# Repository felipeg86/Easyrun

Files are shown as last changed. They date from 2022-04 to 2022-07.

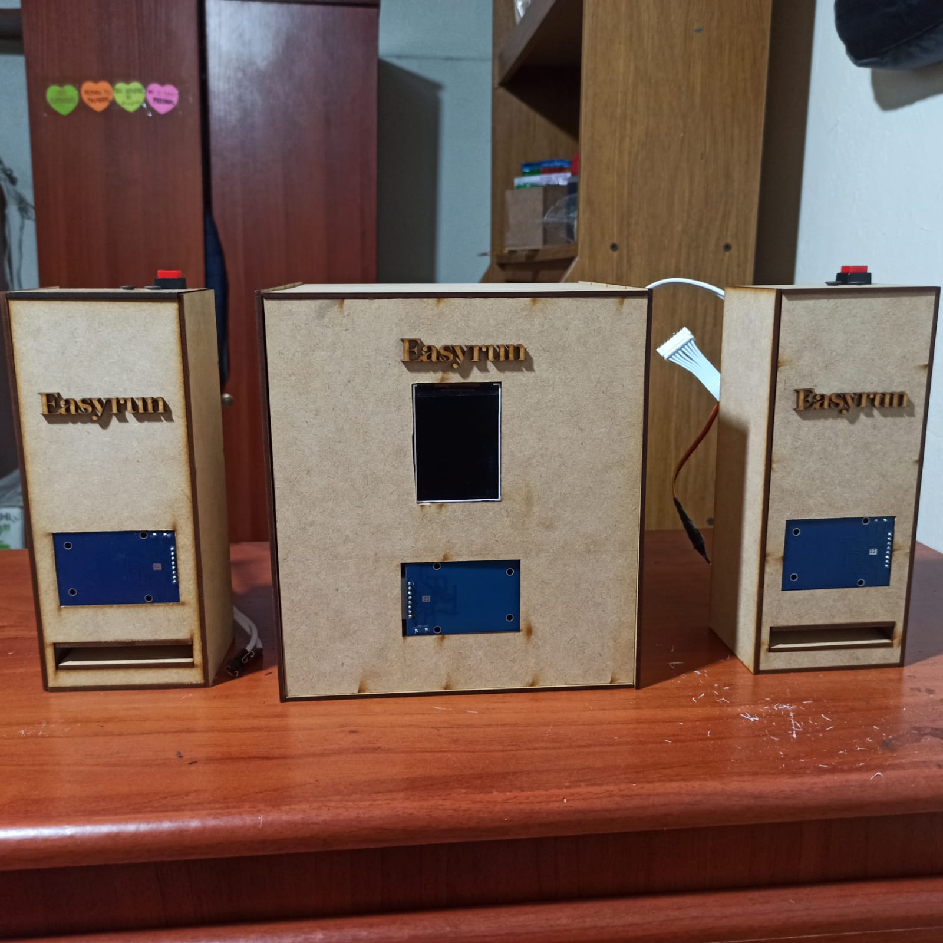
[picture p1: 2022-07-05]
Images/Resultado Final.jpg

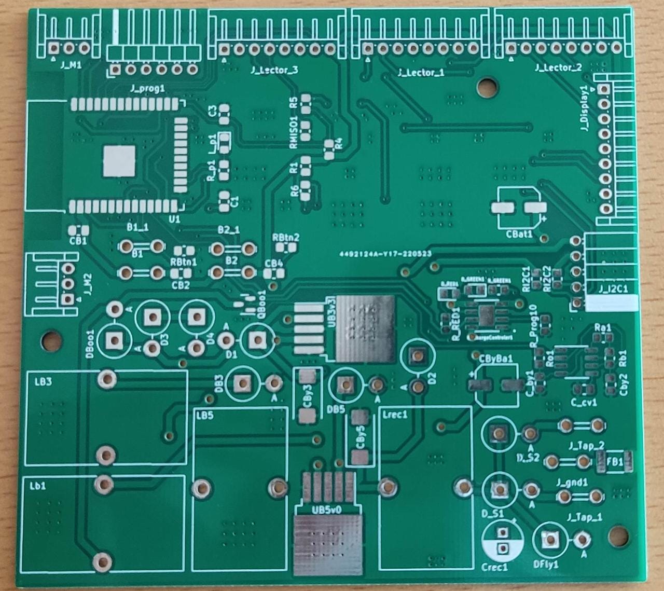
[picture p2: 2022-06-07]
Images/Fabricación placa 2_0.jpeg

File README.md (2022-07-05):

# Easyrun :bike:

Sistema de automatización de préstamo de bicicletas dentro del campus de la Universidad Nacional de Colombia, incorporando la conexión entre estaciones y facilitando el proceso que a la fecha se implementa. El sistema tiene como objetivo principal, reducir los tiempos en el uso del servicio, especialmente en los puntos de prestámo y entrega, además de permitir un control sobre la trazabilidad de cada bicicleta.

Integrantes: 

* Ana Milena Espinosa Jiménez
* Laura Valentina Moreno Castro
* Johan Stevens Higuera Espinel
* Omar Andrés Cely Villate
* Juan Felipe González Pardo
* Kishvari Osorio Delgado
* Johan Sebastian Molina Martinez

## Organización del repositorio

El proyecto se organiza en las sigueintes carpetas:

> * En la carpeta "[Circuit Design](https://github.com/felipeg86/Easyrun/tree/main/Circuit%20Design)" se encuentran las simulaciones, diseños y esquemáticos llevados a cabo en el diseño del hardware del sistema.
> * "[Micropython](https://github.com/felipeg86/Easyrun/tree/main/Micropython)" contiene los scripts utilizados para programar el microcontrolador de la solución.
> * En "[Case Design](https://github.com/felipeg86/Easyrun/tree/main/Case%20Design)" se encuentran los modelos 3D, planos y consideraciones físicas para la cubierta y componentes mecánicos. 
> * "[Budget](https://github.com/felipeg86/Easyrun/tree/main/Budget)" contiene el presupuesto detallado para el desarrollo del prototipo. 
> * "[Imágenes](https://github.com/felipeg86/Easyrun/tree/main/Images)" almacena las imágenes utilizadas en la documentación y en los archivos readme de cada sección.

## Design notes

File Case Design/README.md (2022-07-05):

# Diseño de la carcasa
Para el diseño de las carcasas del sistema, se descargó el modelo 3D de la placa del circuito en KiCad y se cargaron los componentes en 3D, lo cual permitió diseñar en el programa Fusion 360 una caja para la PCB y otra para el seguro. El procedimiento de estos diseños se encuentra en el apartado "Diseño de la Caja" en la wiki del proyecto.

## Contenido Carpeta
La presenta carpeta contiene los siguientes archivos:
 * Archivo modelo 3D placa del circuito (.step)
 * Archivo Corte Láser y modelo 3D para la caja para la PCB (.dxf -- .step)
 * Archivo Corte Láser y modelo 3D para la caja del sistema de bloqueo (.dxf -- .step)
 * Archivo Corte Láser y modelo 3D para el seguro de la bicicleta (.dxf -- .step)

## Diseño Final Caja para la PCB



## Diseño Final Caja para el Sistema de Bloqueo


## Animación Soporte para el Seguro de la Bicicleta
 

## Enlaces de Referencia para los Modelos 3D de los Componentes utilizados:
* Lector y Tarjeta RFID: [https://grabcad.com/library/mfrc522-simple-model-1](https://grabcad.com/library/mfrc522-simple-model-1) 
* Bobina: [https://www.3dcontentcentral.com/download-model.aspx?catalogid=171&id=808719](https://www.3dcontentcentral.com/download-model.aspx?catalogid=171&id=808719) 
* Conector AC: [https://grabcad.com/library/ac-power-socket-3-pin-250v-10a-ac-17-iec3-c14-1](https://grabcad.com/library/ac-power-socket-3-pin-250v-10a-ac-17-iec3-c14-1)
* Tranformador: [https://grabcad.com/library/transformador-chapas-n-75-1](https://grabcad.com/library/transformador-chapas-n-75-1)
* Display: [https://grabcad.com/library/tft-3-5-spi-480x320-v2-0-1](https://grabcad.com/library/tft-3-5-spi-480x320-v2-0-1)
* Interruptor: [https://grabcad.com/library/push-button-switch-with-led-1](https://grabcad.com/library/push-button-switch-with-led-1)

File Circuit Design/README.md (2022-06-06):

## Organización de la carpeta
### En "[Datasheets](https://github.com/felipeg86/Easyrun/tree/main/Circuit%20Design/Datasheets)" se presentan las hojas de datos y especificaciones de algunos de los componentes de hardware utilizados en la solución.
### "[LTspice Simulations](https://github.com/felipeg86/Easyrun/tree/main/Circuit%20Design/LTspice%20Simulations)" contiene las simulaciones realizadas para el diseño y validación de algunos de los subsistemas.
### "[Final Schematic](https://github.com/felipeg86/Easyrun/tree/main/Circuit%20Design/Final%20Schematic)" almacena los archivos de diseño y fabricación de la placa de circuito impreso del sistema.

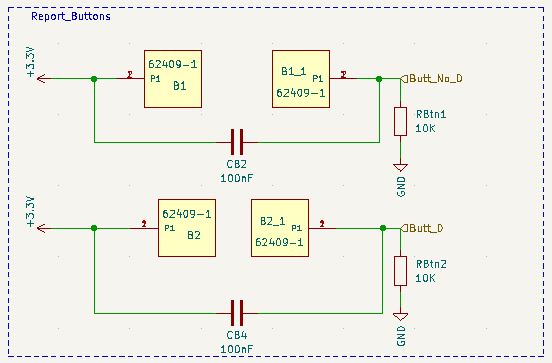
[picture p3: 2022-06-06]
Images/Botones_reporte.JPG

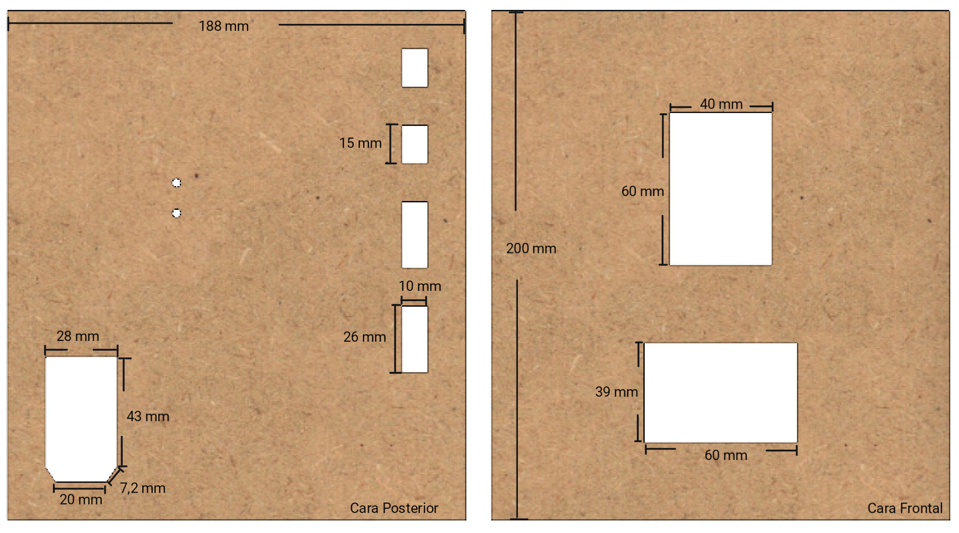
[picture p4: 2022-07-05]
Images/posterior frontal.png

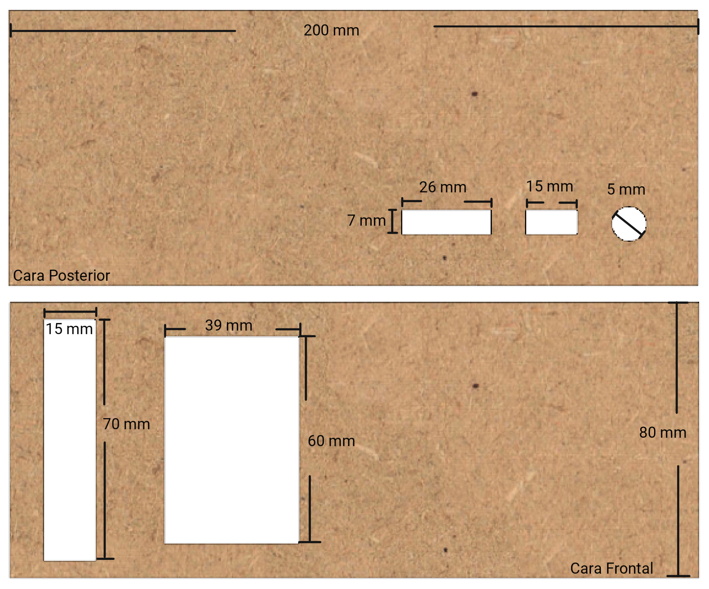
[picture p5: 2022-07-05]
Images/SEGURO1 posterior frontal.png

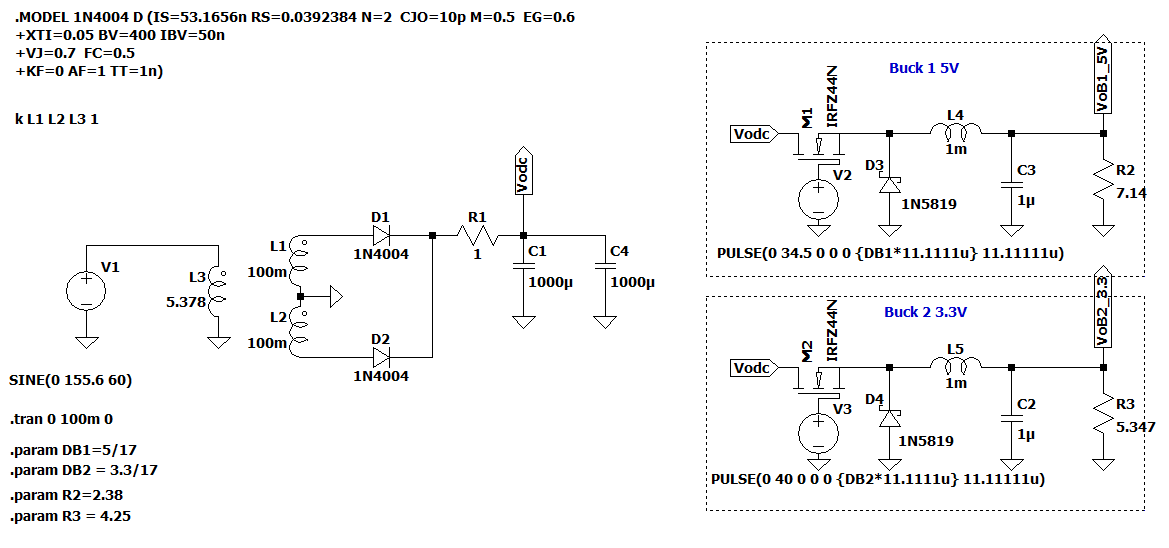
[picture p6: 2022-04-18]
Images/Simulation Power Suply.png

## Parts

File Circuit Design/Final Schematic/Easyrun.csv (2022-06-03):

Source: | Easyrun.kicad_sch
Date: | mar 24 may 2022 09:25:52
Component Count: | 75
Ref | Qnty | Value | Cmp name | Footprint | Description | Vendor
B1, B2, | 2 | 62409-1 | 62409-1 | TE_62409-1
B1_1, | 1 | 62409-1 | 62409-1 | TE_62409-1
B2_1, | 1 | 62409-1 | 62409-1 | TE_62409-1
BProg1, | 1 | SW_DIP_x02 | SW_DIP_x01 | Button_Switch_SMD:SW_SPST_CK_RS282G05A3 | 1x DIP Switch, Single Pole Single Throw (SPST) switch, small symbol
BRst1, | 1 | SW_DIP_x01 | SW_DIP_x01 | Button_Switch_SMD:SW_SPST_CK_RS282G05A3 | 1x DIP Switch, Single Pole Single Throw (SPST) switch, small symbol
BT1, | 1 | Battery_Cell | Battery_Cell | Battery:BatteryHolder_MPD_BH-18650-PC2 | Single-cell battery
C1, C3, | 2 | 100nF | C | Capacitor_SMD:C_0805_2012Metric_Pad1.18x1.45mm_HandSolder | Unpolarized capacitor
C_b1, | 1 | C_Polarized | C_Polarized | Capacitor_SMD:CP_Elec_6.3x5.8 | Polarized capacitor
C_by1, | 1 | 10n | C | Capacitor_SMD:C_0805_2012Metric_Pad1.18x1.45mm_HandSolder | Unpolarized capacitor
C_cv1, | 1 | 10n | C | Capacitor_SMD:C_0805_2012Metric_Pad1.18x1.45mm_HandSolder | Unpolarized capacitor
CB1, CB2, CB4, | 3 | 100nF | C | Capacitor_SMD:C_0805_2012Metric_Pad1.18x1.45mm_HandSolder | Unpolarized capacitor
CB3, CB5, | 2 | 22u | C_Polarized | Capacitor_SMD:CP_Elec_6.3x5.8 | Polarized capacitor
CBat1, | 1 | 10u | C_Polarized | Capacitor_SMD:CP_Elec_6.3x5.8 | Polarized capacitor
Cby2, | 1 | 0.1u | C | Capacitor_SMD:C_0805_2012Metric_Pad1.18x1.45mm_HandSolder | Unpolarized capacitor
CBy3, CBy5, | 2 | 47u | C_Polarized | Capacitor_Tantalum_SMD:CP_EIA-7343-43_Kemet-X_Pad2.25x2.55mm_HandSolder | Polarized capacitor
CByBa1, | 1 | 10u | C_Polarized | Capacitor_SMD:CP_Elec_6.3x5.8 | Polarized capacitor
Crec1, | 1 | 100u | C_Polarized | Capacitor_THT:CP_Radial_D6.3mm_P2.50mm | Polarized capacitor
D1, D2, D3, D4, | 4 | 1N5822 | 1N5822 | Diode_THT:D_DO-201AE_P5.08mm_Vertical_AnodeUp | 40V 3A Schottky Barrier Rectifier Diode, DO-201AD
D_GREEN1, | 1 | LED | LED | LED_SMD:LED_0805_2012Metric_Pad1.15x1.40mm_HandSolder | Light emitting diode
D_RED1, | 1 | LED | LED | LED_SMD:LED_0805_2012Metric_Pad1.15x1.40mm_HandSolder | Light emitting diode
D_S1, D_S2, | 2 | 1N5822 | 1N5822 | Diode_THT:D_DO-201AE_P5.08mm_Vertical_AnodeUp | 40V 3A Schottky Barrier Rectifier Diode, DO-201AD
DB3, DB5, | 2 | 1N5822 | 1N5822 | Diode_THT:D_DO-201AE_P5.08mm_Vertical_AnodeUp | 40V 3A Schottky Barrier Rectifier Diode, DO-201AD
DBoo1, | 1 | 1N5819 | 1N5819 | Diode_THT:D_DO-201AE_P5.08mm_Vertical_AnodeUp | 40V 1A Schottky Barrier Rectifier Diode, DO-41
DFly1, | 1 | 1N5822 | 1N5822 | Diode_THT:D_DO-201AE_P5.08mm_Vertical_AnodeUp | 40V 3A Schottky Barrier Rectifier Diode, DO-201AD
FB1, | 1 | FerriteBead | FerriteBead | Resistor_SMD:R_1812_4532Metric_Pad1.30x3.40mm_HandSolder | Ferrite bead
J_Display1, | 1 | Conn_01x09 | Conn_01x09 | Connector_JST:JST_EH_S9B-EH_1x09_P2.50mm_Horizontal | Generic connector, single row, 01x09, script generated (kicad-library-utils/schlib/autogen/connector/)
J_gnd1, | 1 | 62409-1 | 62409-1 | TE_62409-1
J_I2C1, | 1 | Conn_01x05_Male | Conn_01x05_Male | Connector_PinSocket_2.54mm:PinSocket_1x05_P2.54mm_Horizontal | Generic connector, single row, 01x05, script generated (kicad-library-utils/schlib/autogen/connector/)
J_Lector_1, J_Lector_2, J_Lector_3, | 3 | Conn_01x08 | Conn_01x08 | Connector_JST:JST_EH_S8B-EH_1x08_P2.50mm_Horizontal | Generic connector, single row, 01x08, script generated (kicad-library-utils/schlib/autogen/connector/)
J_M1, J_M2, | 2 | Conn_01x03 | Conn_01x03 | Connector_JST:JST_EH_S3B-EH_1x03_P2.50mm_Horizontal | Generic connector, single row, 01x03, script generated (kicad-library-utils/schlib/autogen/connector/)
J_prog1, | 1 | Conn_01x06_Male | Conn_01x06_Male | Connector_PinHeader_2.54mm:PinHeader_1x06_P2.54mm_Horizontal | Generic connector, single row, 01x06, script generated (kicad-library-utils/schlib/autogen/connector/)
J_Tap_1, J_Tap_2, | 2 | 62409-1 | 62409-1 | TE_62409-1
L_p1, | 1 | LED | LED | LED_SMD:LED_0805_2012Metric_Pad1.15x1.40mm_HandSolder | Light emitting diode
Lb1, | 1 | 100u | L | Inductor_THT:L_Toroid_Vertical_L25.4mm_W14.7mm_P12.20mm_Vishay_TJ5_BigPads | Inductor
LB3, LB5, | 2 | 100u | L | Inductor_THT:L_Toroid_Vertical_L25.4mm_W14.7mm_P12.20mm_Vishay_TJ5_BigPads | Inductor
Lrec1, | 1 | 150m | L | Inductor_THT:L_Toroid_Vertical_L25.4mm_W14.7mm_P12.20mm_Vishay_TJ5_BigPads | Inductor
QBoo1, | 1 | SI2302 | Q_NMOS_GSD | Package_TO_SOT_SMD:SOT-23 | N-MOSFET transistor, gate/source/drain
R1, R4, | 2 | 10K | R | Resistor_SMD:R_0805_2012Metric_Pad1.20x1.40mm_HandSolder | Resistor
R5, R6, | 2 | 220 | R | Resistor_SMD:R_0805_2012Metric_Pad1.20x1.40mm_HandSolder | Resistor
R_GREEN1, | 1 | 1k | R | Resistor_SMD:R_0805_2012Metric_Pad1.20x1.40mm_HandSolder | Resistor
R_p1, | 1 | 47 | R | Resistor_SMD:R_0805_2012Metric_Pad1.20x1.40mm_HandSolder | Resistor
R_Prog10, | 1 | 10k | R | Resistor_SMD:R_0805_2012Metric_Pad1.20x1.40mm_HandSolder | Resistor
R_RED1, | 1 | 1k | R | Resistor_SMD:R_0805_2012Metric_Pad1.20x1.40mm_HandSolder | Resistor
Ra1, | 1 | 47 | R | Resistor_SMD:R_0805_2012Metric_Pad1.20x1.40mm_HandSolder | Resistor
Rb1, | 1 | 100 | R | Resistor_SMD:R_0805_2012Metric_Pad1.20x1.40mm_HandSolder | Resistor
RBtn1, RBtn2, | 2 | 10K | R | Resistor_SMD:R_0805_2012Metric_Pad1.20x1.40mm_HandSolder | Resistor
RI2C1, RI2C2, | 2 | 10k | R | Resistor_SMD:R_0805_2012Metric_Pad1.20x1.40mm_HandSolder | Resistor
RMISO1, | 1 | 10k | R | Resistor_SMD:R_0805_2012Metric_Pad1.20x1.40mm_HandSolder | Resistor
Ro1, | 1 | 1k | R | Resistor_SMD:R_0805_2012Metric_Pad1.20x1.40mm_HandSolder | Resistor
SWRec1, | 1 | SW_DIP_x01 | SW_DIP_x01 | Connector_PinHeader_2.54mm:PinHeader_1x02_P2.54mm_Vertical_SMD_Pin1Left | 1x DIP Switch, Single Pole Single Throw (SPST) switch, small symbol
U1, | 1 | ESP32-WROOM-32 | ESP32-WROOM-32 | RF_Module:ESP32-WROOM-32 | RF Module, ESP32-D0WDQ6 SoC, Wi-Fi 802.11b/g/n, Bluetooth, BLE, 32-bit, 2.7-3.6V, onboard antenna, SMD
U_555, | 1 | LM555xM | LM555xM | Package_SO:SOIC-8_3.9x4.9mm_P1.27mm | Timer, 555 compatible, SOIC-8
U_ChargeControler1, | 1 | TP4056 | TP4056 | TP4056_Bcharge:SOP127P600X175-9N
UB3v3, | 1 | LM2576S-3.3 | LM2576S-3.3 | Package_TO_SOT_SMD:TO-263-5_TabPin3 | 3.3V, 3A SIMPLE SWITCHER® Step-Down Voltage Regulator, TO-263
UB5v0, | 1 | LM2576S-5 | LM2576S-5 | Package_TO_SOT_SMD:TO-263-5_TabPin3 | 5V, 3A SIMPLE SWITCHER® Step-Down Voltage Regulator, TO-263

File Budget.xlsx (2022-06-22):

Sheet: Presupuesto
Item | Qty | Reference(s) | Voltage (V) | Current (A) | Power (W) | Value | Companie | Unit Price | Total Quantity | We have | Condition | Who? | Total
1 | 1 | MicroUSB a Serial CP2102 | 3.3 | 0.02 | 0.066 | $9000 | Ferretrónica | $9000 | 2 | 0 | 2 | Omar | $18000
2 | 1 | ESP32 Wroom 32 | 3.3 | 0.17 | 0.561 | $18000 | Mactrónica | $18000 | 2 |  | 2 | Felipe | $36000
3 | 1 | TFT ILI9341 | 3.3 | 0.06 | 0.198 | $45000 | Mercado Libre | $45000 | 2 |  | 2 | Kish | $90000
4 | 1 | Transformador 12V 1A con Tap Central | - | - | - | $37000 | Ferretrónica | $37000 | 2 |  | 2 | Omar | $74000
5 | 1 | Cable de alimentación C14 | - | - | - | $9900 | Mercado Libre | $9900 | 2 |  | 2 | Felipe | $19800
6 | 1 | Conector de poder ACLEC320C14 | - | - | - | $8800 | Mercado Libre | $8800 | 2 |  | 2 | Felipe | $17600
7 | 2 | Servomotor | 5 | 0.7 | 3.5 | $11000 | Mercado Libre | $11000 | 4 |  | 4 | Sebastian | $44000
8 | 2 | Mecanismo piñon cremallera | - | - | - | $11500 | Mercado Libre | $11500 | 4 |  | 4 | Sebastian | $46000
9 | 2 | Pasador | - | - | - | $4000 | Ferreteria | $4000 | 4 |  | 4 | Sebastian | $16000
10 | 3 | Kit lector RFID RC522 | 3.3 | 0.03 | 0.099 | $15000 | Sigma | $15000 | 6 |  | 6 | Johan | $90000
11 | 7 | Terminal faston macho para PCB | - | - | - | $214.23 | Vistronica | $214.23 | 14 | 0 | 14 | Omar | $2999.22
12 | 7 | Terminal Faston Hembra | - | - | - | $200 | Vistronica | $200 | 14 | 0 | 14 | Omar | $2800
13 | 3 | Alambre AWG 18 (por metros) | - | - | - | $1000 | Ferreteria | $1000 | 6 | 0 | 6 | Sebastian | $6000
14 | 2 | Pulsador 3x6x2.5 mm SMD | - | - | - | $119.05 | Vistronica | $119.05 | 4 | 0 | 4 | Omar | $476.2
15 | 1 | PORTAPILAS 18650 | - | - | - | $5000 | Mactrónica | $5000 | 2 | 0 | 2 | Felipe | $10000
16 | 1 | Capacitor Cerámico 100 nF 50V SAMSUNG SMD 0805 x10 | - | - | - | $996.63 | Vistronica | $996.63 | 2 | 0 | 2 | Omar | $1993.26
17 | 1 | Capacitor Cerámico 10 nF 50V YAGEO SMD 0805 x10 | - | - | - | $484.33 | Vistronica | $484.33 | 2 | 0 | 2 | Omar | $968.66
18 | 3 | COND 47UF 16V | - | - | - | $476 | Sigma | $476 | 6 | 0 | 6 | Johan | $2856
19 | 2 | Capacitor Electrolítico De Aluminio 10 uF 50V 5x5 mm SMD | - | - | - | $217.18 | Vistronica | $217.18 | 4 | 0 | 4 | Omar | $868.72
20 | 2 | Condensador De Tantalio 47 uF 25V SMD EIA7343-43 | - | - | - | $597.38 | Vistronica | $597.38 | 4 | 0 | 4 | Omar | $2389.52
21 | 1 | Condensador Electrolitico 100uF x 35V | - | - | - | $250 | Ferretrónica | $250 | 2 | 0 | 2 | Omar | $500
22 | 11 | Diodo Rectificador De Barrera 1N5822 | - | - | - | $476 | Vistronica | $476 | 22 | 0 | 22 | Omar | $10472
23 | 2 | LED 0805 ROJO | - | - | - | $238 | Sigma | $238 | 4 | 0 | 4 | Johan | $952
24 | 2 | LED 0805 Verde | - | - | - | $238 | Sigma | $238 | 4 | 0 | 4 | Johan | $952
25 | 1 | MI1812K121R | - | - | - | $2142 | Sigma | $2142 | 2 | 0 | 2 | Johan | $4284
26 | 6 | CABLE CON CONECTOR XH2.54MM 8P | - | - | - | $1794 | Vistronica | $1794 | 12 | 0 | 12 | Omar | $21528
27 | 6 | CONECTOR XH2.54 8P MACHO INCLINADO 90 GRADOS | - | - | - | $595 | Vistronica | $595 | 12 | 0 | 12 | Omar | $7140
28 | 1 | CABLE CON CONECTOR XH2.54MM 9P | - | - | - | $2181 | Vistronica | $2181 | 2 | 0 | 2 | Omar | $4362
29 | 2 | CONECTOR MACHO XH2.54 9P | - | - | - | $307 | Vistronica | $307 | 4 | 0 | 4 | Omar | $1228
30 | 2 | CABLE CON CONECTOR XH2.54 MM 3P | - | - | - | $974 | Vistronica | $974 | 4 | 0 | 4 | Omar | $3896
31 | 3 | CONECTOR MACHO XH2.54 8P | - | - | - | $307 | Vistronica | $307 | 6 | 0 | 6 | Omar | $1842
32 | 6 | CONECTOR MACHO XH2.54 3P | - | - | - | $221 | Vistronica | $221 | 12 | 0 | 12 | Omar | $2652
33 | 2 | LED 0805 AZUL | - | - | - | $238 | Sigma | $238 | 4 | 0 | 4 | Johan | $952
34 | 3 | Inductor 100uh 6a Bobina Con Nucleo Toroidal De Ferrita | - | - | - | $7212 | Mercado Libre | $7212 | 6 | 6 | 0 | Felipe | $43272
35 | 2 | TRANSISTOR MOSFET SI2302/A2SHB 20V 3A SMD SOT-23 | - | - | - | $174.93 | Vistronica | $174.93 | 4 | 0 | 4 | Omar | $699.72
36 | 1 | Resistencias 10 KOHM SMD 0805 1/8W 1% x10 | - | - | - | $290.36 | Vistronica | $290.36 | 2 | 0 | 2 | Omar | $580.72
37 | 1 | Resistencias 1 KOHM SMD 0805 1/8W 1% x10 | - | - | - | $290 | Vistronica | $290 | 2 | 0 | 2 | Omar | $580
38 | 1 | Resistencias 47 KOHM SMD 0805 1/8W 1% x10 | - | - | - | $290 | Vistronica | $290 | 2 | 0 | 2 | Omar | $580
39 | 1 | Resistencias 220 OHM SMD 0805 1/8W 1% x10 | - | - | - | $290 | Vistronica | $290 | 2 | 0 | 2 | Omar | $580
40 | 10 | R0805 100 OHM | - | - | - | $48 | Sigma | $48 | 20 | 0 | 20 | Johan | $960
41 | 1 | Conector Jumper 2.54 mm 2P Negro | - | - | - | $119 | Vistronica | $119 | 2 | 0 | 2 | Omar | $238
42 | 1 | Regleta Conector 1*40P 2.54MM Macho-Macho | - | - | - | $312.97 | Vistronica | $312.97 | 2 | 0 | 2 | Omar | $625.94
43 | 1 | TEMPORIZADOR ELÉCTRICO NE555 SMD SOIC-8 | - | - | - | $341.23 | Vistronica | $341.23 | 2 | 0 | 2 | Omar | $682.46
44 | 1 | TP4056 | - | - | - | $2142 | Sigma | $2142 | 2 | 0 | 2 | Johan | $4284
45 | 1 | LM2576S-5.0 | - | - | - | $3332 | Sigma | $3332 | 2 | 0 | 2 | Johan | $6664
46 | 1 | LM2576S-3.3 | - | - | - | $3451 | Sigma | $3451 | 2 | 0 | 2 | Johan | $6902
47 | 1 | EA77-625 | - | - | - | $47600 | Sigma | $47600 | 2 | 0 | 2 | Johan | $95200
48 | 1 | CP2102 | - | - | - | $19180 | Ferretrónica | $19180 | 1 | 0 | 1 | Laura | $19180
Total |  |  |  |  |  |  |  |  |  |  |  |  | $724540.42
 |  |  |  |  |  |  |  |  |  |  |  | Quote | $103505.7743
 |  |  |  |  |  | Each person |  | Quote
 |  |  |  |  |  | Kish |  | $103505.7743
 |  |  |  |  |  | Omar |  | $103505.7743
 |  |  |  |  |  | Felipe |  | $103505.7743
 |  |  |  |  |  | Laura |  | $103505.7743
 |  |  |  |  |  | Ana |  | $103505.7743
 |  |  |  |  |  | Johan |  | $103505.7743
 |  |  |  |  |  | Sebastián |  | $103505.7743

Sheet: Vistronica
Item | Qty | Reference(s) | Value | Companie | Unit Price | Total Quantity | We have | Condition | Who? | Total
11 | 7 | Terminal faston macho para PCB | $214.23 | Vistronica | $214.23 | 14 | 0 | 14 | Omar | $2999.22
12 | 7 | Terminal Faston Hembra | $200 | Vistronica | $200 | 14 | 0 | 14 | Omar | $2800
14 | 2 | Pulsador 3x6x2.5 mm SMD | $119.05 | Vistronica | $119.05 | 4 | 0 | 4 | Omar | $476.2
16 | 1 | Capacitor Cerámico 100 nF 50V SAMSUNG SMD 0805 x10 | $996.63 | Vistronica | $996.63 | 2 | 0 | 2 | Omar | $1993.26
17 | 1 | Capacitor Cerámico 10 nF 50V YAGEO SMD 0805 x10 | $484.33 | Vistronica | $484.33 | 2 | 0 | 2 | Omar | $968.66
19 | 2 | Capacitor Electrolítico De Aluminio 10 uF 50V 5x5 mm SMD | $217.18 | Vistronica | $217.18 | 4 | 0 | 4 | Omar | $868.72
20 | 2 | Condensador De Tantalio 47 uF 25V SMD EIA7343-43 | $597.38 | Vistronica | $597.38 | 4 | 0 | 4 | Omar | $2389.52
22 | 11 | Diodo Rectificador De Barrera 1N5822 | $476 | Vistronica | $476 | 22 | 0 | 22 | Omar | $10472
26 | 6 | CABLE CON CONECTOR XH2.54MM 8P | $1794 | Vistronica | $1794 | 12 | 0 | 12 | Omar | $21528
27 | 6 | CONECTOR XH2.54 8P MACHO INCLINADO 90 GRADOS | $595 | Vistronica | $595 | 12 | 0 | 12 | Omar | $7140
28 | 1 | CABLE CON CONECTOR XH2.54MM 9P | $2181 | Vistronica | $2181 | 2 | 0 | 2 | Omar | $4362
29 | 2 | CONECTOR MACHO XH2.54 9P | $307 | Vistronica | $307 | 4 | 0 | 4 | Omar | $1228
30 | 2 | CABLE CON CONECTOR XH2.54 MM 3P | $974 | Vistronica | $974 | 4 | 0 | 4 | Omar | $3896
31 | 3 | CONECTOR MACHO XH2.54 8P | $307 | Vistronica | $307 | 6 | 0 | 6 | Omar | $1842
32 | 6 | CONECTOR MACHO XH2.54 3P | $221 | Vistronica | $221 | 12 | 0 | 12 | Omar | $2652
35 | 2 | TRANSISTOR MOSFET SI2302/A2SHB 20V 3A SMD SOT-23 | $174.93 | Vistronica | $174.93 | 4 | 0 | 4 | Omar | $699.72
36 | 1 | Resistencias 10 KOHM SMD 0805 1/8W 1% x10 | $290.36 | Vistronica | $290.36 | 2 | 0 | 2 | Omar | $580.72
37 | 1 | Resistencias 1 KOHM SMD 0805 1/8W 1% x10 | $290 | Vistronica | $290 | 2 | 0 | 2 | Omar | $580
38 | 1 | Resistencias 47 KOHM SMD 0805 1/8W 1% x10 | $290 | Vistronica | $290 | 2 | 0 | 2 | Omar | $580
39 | 1 | Resistencias 220 OHM SMD 0805 1/8W 1% x10 | $290 | Vistronica | $290 | 2 | 0 | 2 | Omar | $580
41 | 1 | Conector Jumper 2.54 mm 2P Negro | $119 | Vistronica | $119 | 2 | 0 | 2 | Omar | $238
42 | 1 | Regleta Conector 1*40P 2.54MM Macho-Macho | $312.97 | Vistronica | $312.97 | 2 | 0 | 2 | Omar | $625.94
43 | 1 | TEMPORIZADOR ELÉCTRICO NE555 SMD SOIC-8 | $341.23 | Vistronica | $341.23 | 2 | 0 | 2 | Omar | $682.46
Total |  |  |  |  |  |  |  |  |  | $70182.42

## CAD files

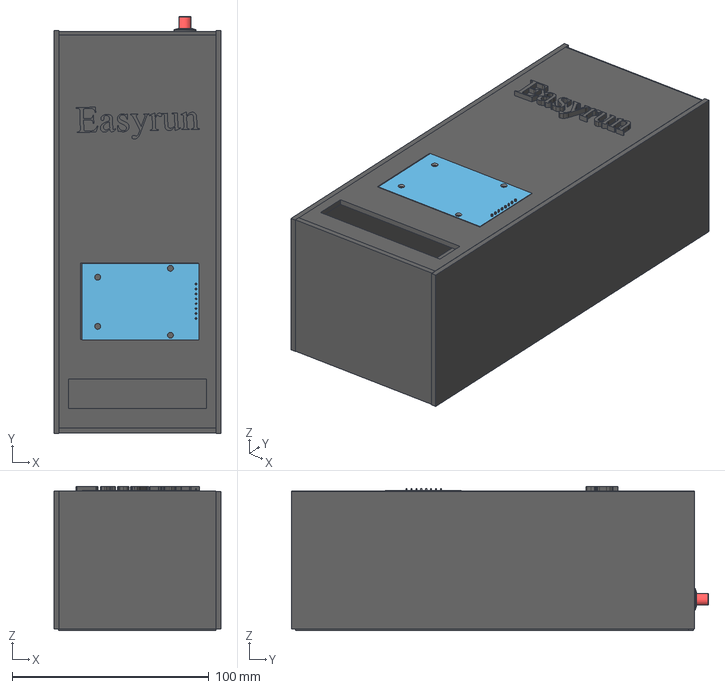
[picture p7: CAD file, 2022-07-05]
Case Design/Modelo 3D Caja Sistema Bloqueo.step
84.7 x 212.0 x 73.4 mm
RFID-RC522 simple
SW_SPST_LED

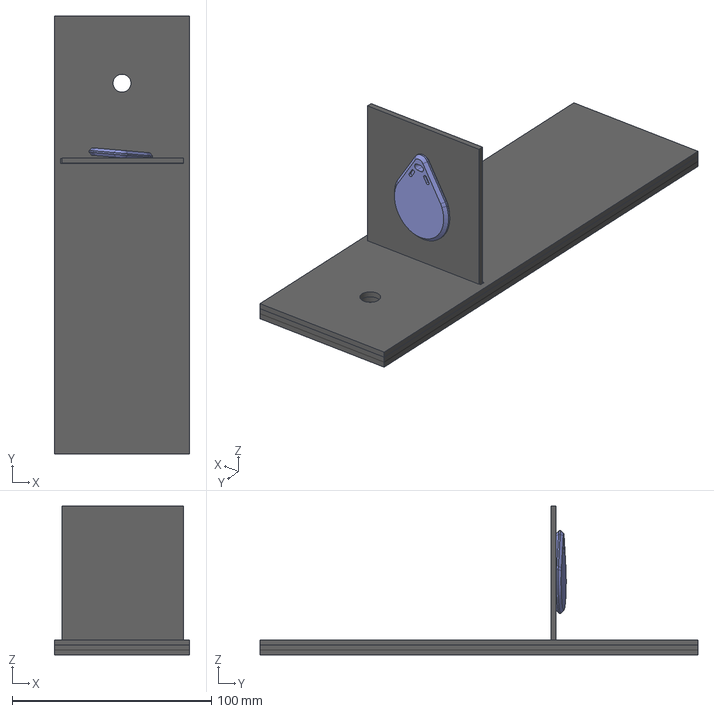
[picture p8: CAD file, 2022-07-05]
Case Design/Modelo 3D Soporte Seguro Bicicleta.step
68.0 x 220.0 x 74.7 mm

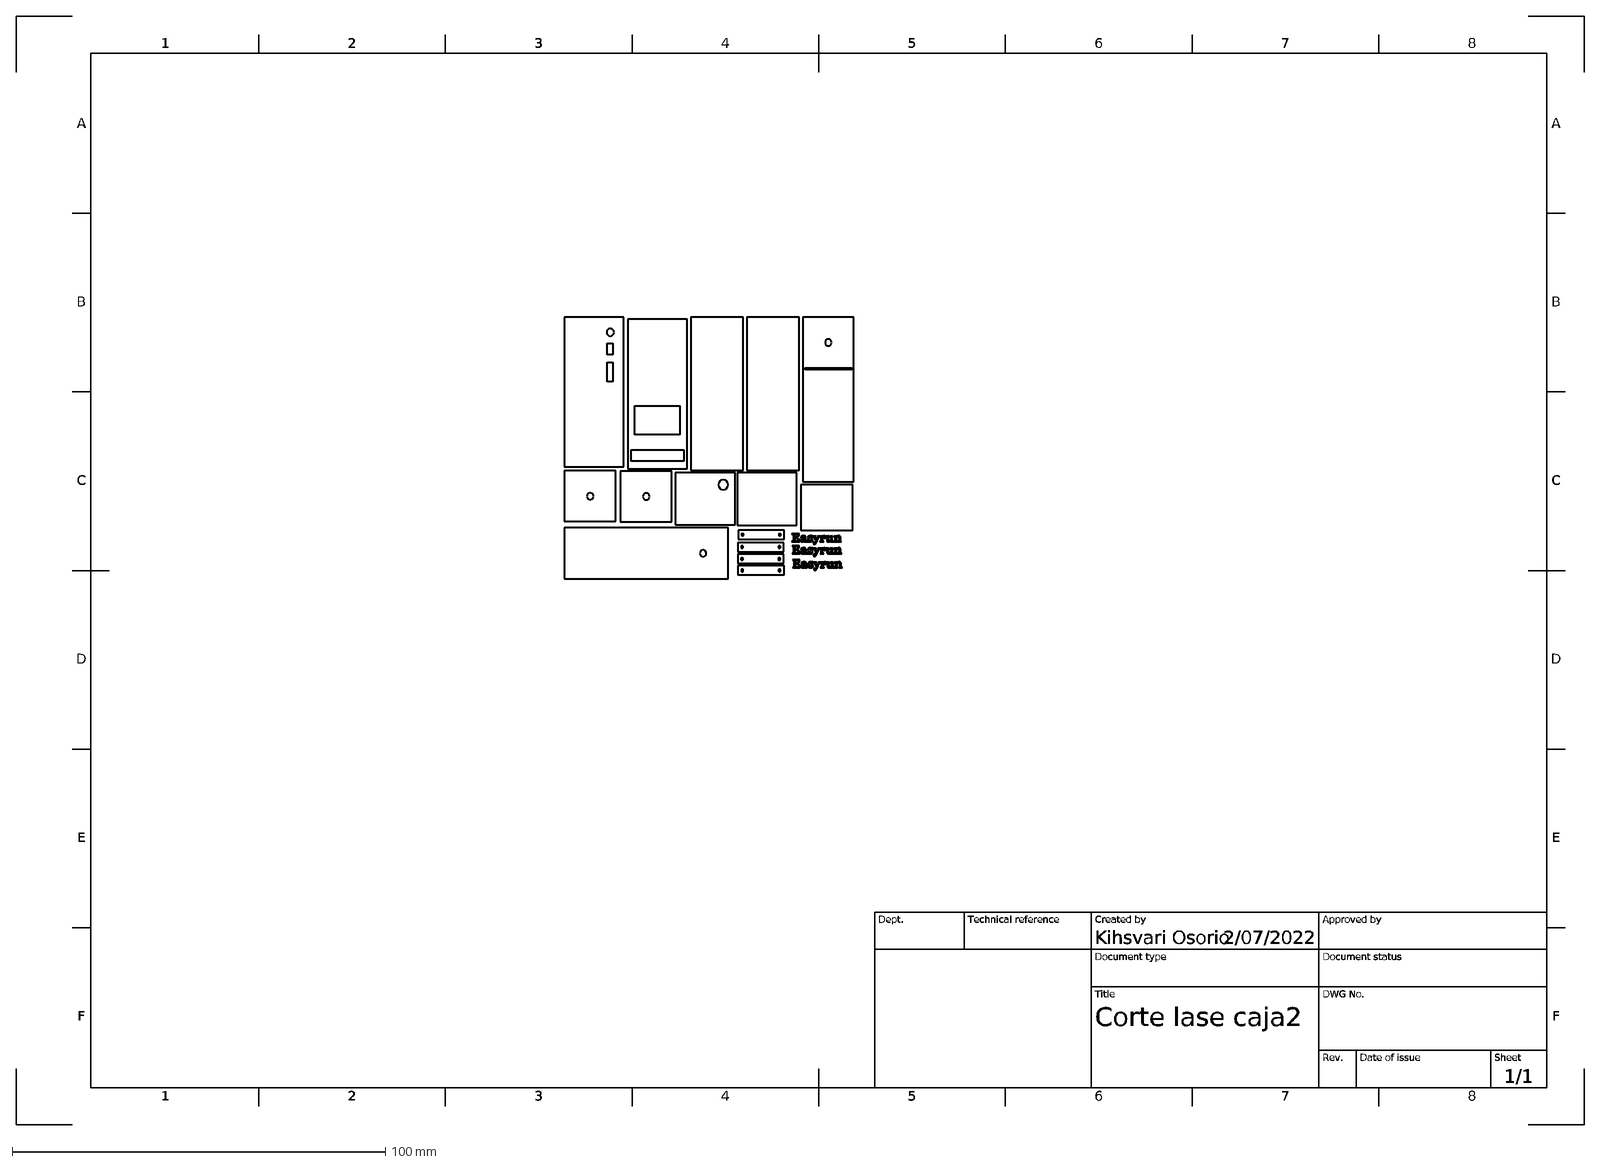
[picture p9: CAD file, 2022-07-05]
Case Design/Corte_laser_sistema_bloqueo.dxf
1
A
2
3
4
5
6
7
8
B
C
D
E
F
2/07/2022
1/1
Corte lase caja2
Kihsvari Osorio
Dept.
Technical reference
Created by
Approved by
Document type
Document status
Title
DWG No.
Rev.
Date of issue
Sheet

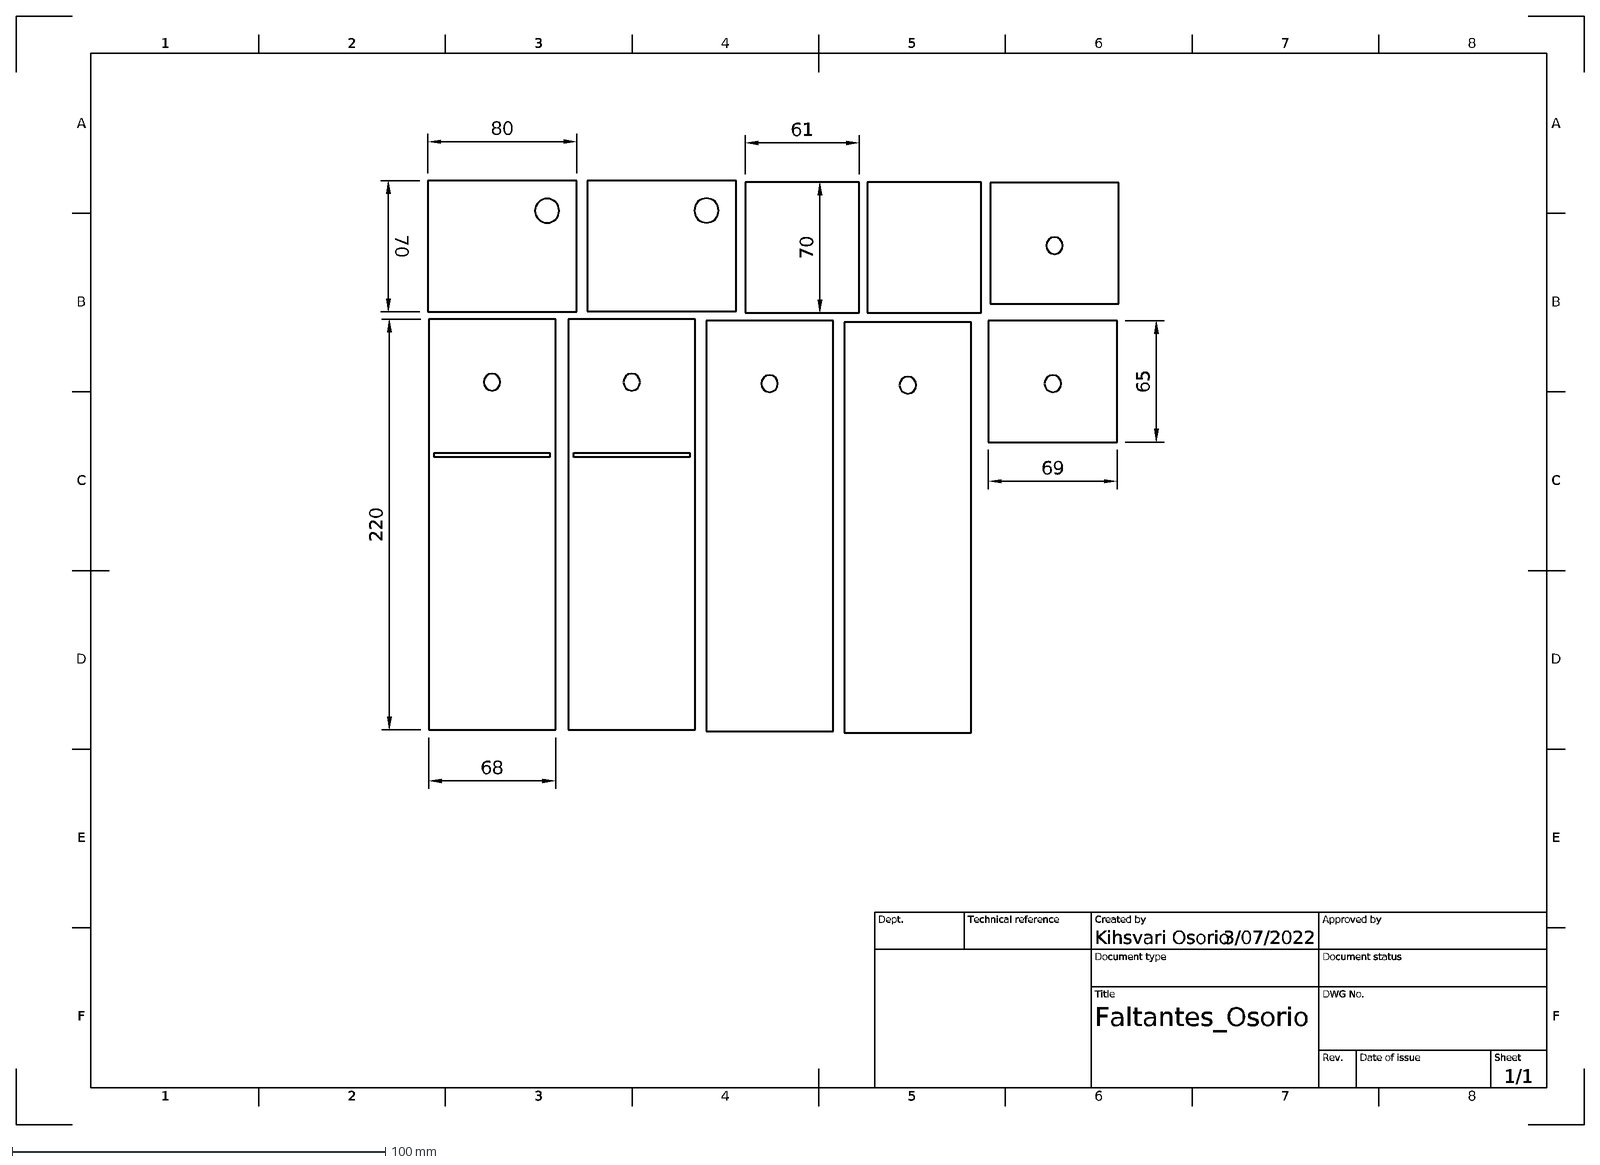
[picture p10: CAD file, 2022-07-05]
Case Design/Corte_laser_soporte.dxf
1
A
2
3
4
5
6
7
8
B
C
D
E
F
3/07/2022
1/1
Faltantes_Osorio
Kihsvari Osorio
Dept.
Technical reference
Created by
Approved by
Document type
Document status
Title
DWG No.
Rev.
Date of issue
Sheet
80
70
220
68
69
65
61

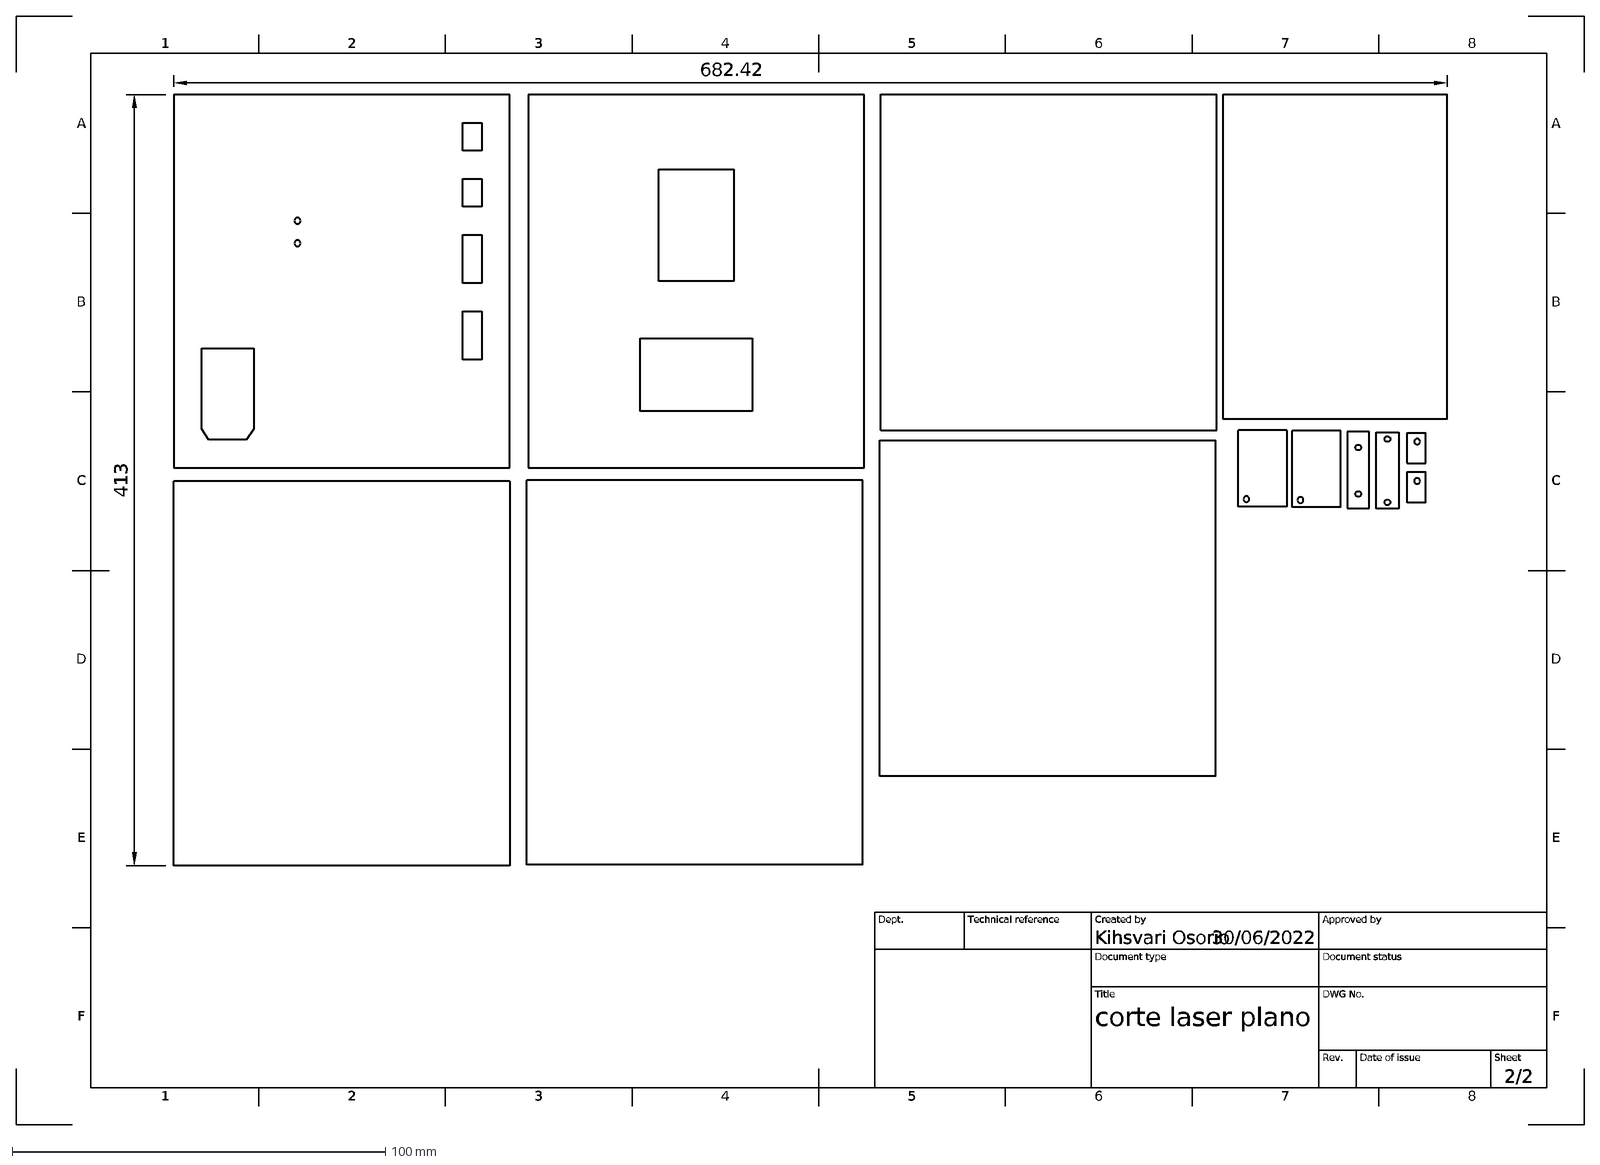
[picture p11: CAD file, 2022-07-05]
Case Design/Corte_laser_PCB.dxf
1
A
2
3
4
5
6
7
8
B
C
D
E
F
30/06/2022
2/2
corte laser plano
Kihsvari Osorio
Dept.
Technical reference
Created by
Approved by
Document type
Document status
Title
DWG No.
Rev.
Date of issue
Sheet
682.42
413

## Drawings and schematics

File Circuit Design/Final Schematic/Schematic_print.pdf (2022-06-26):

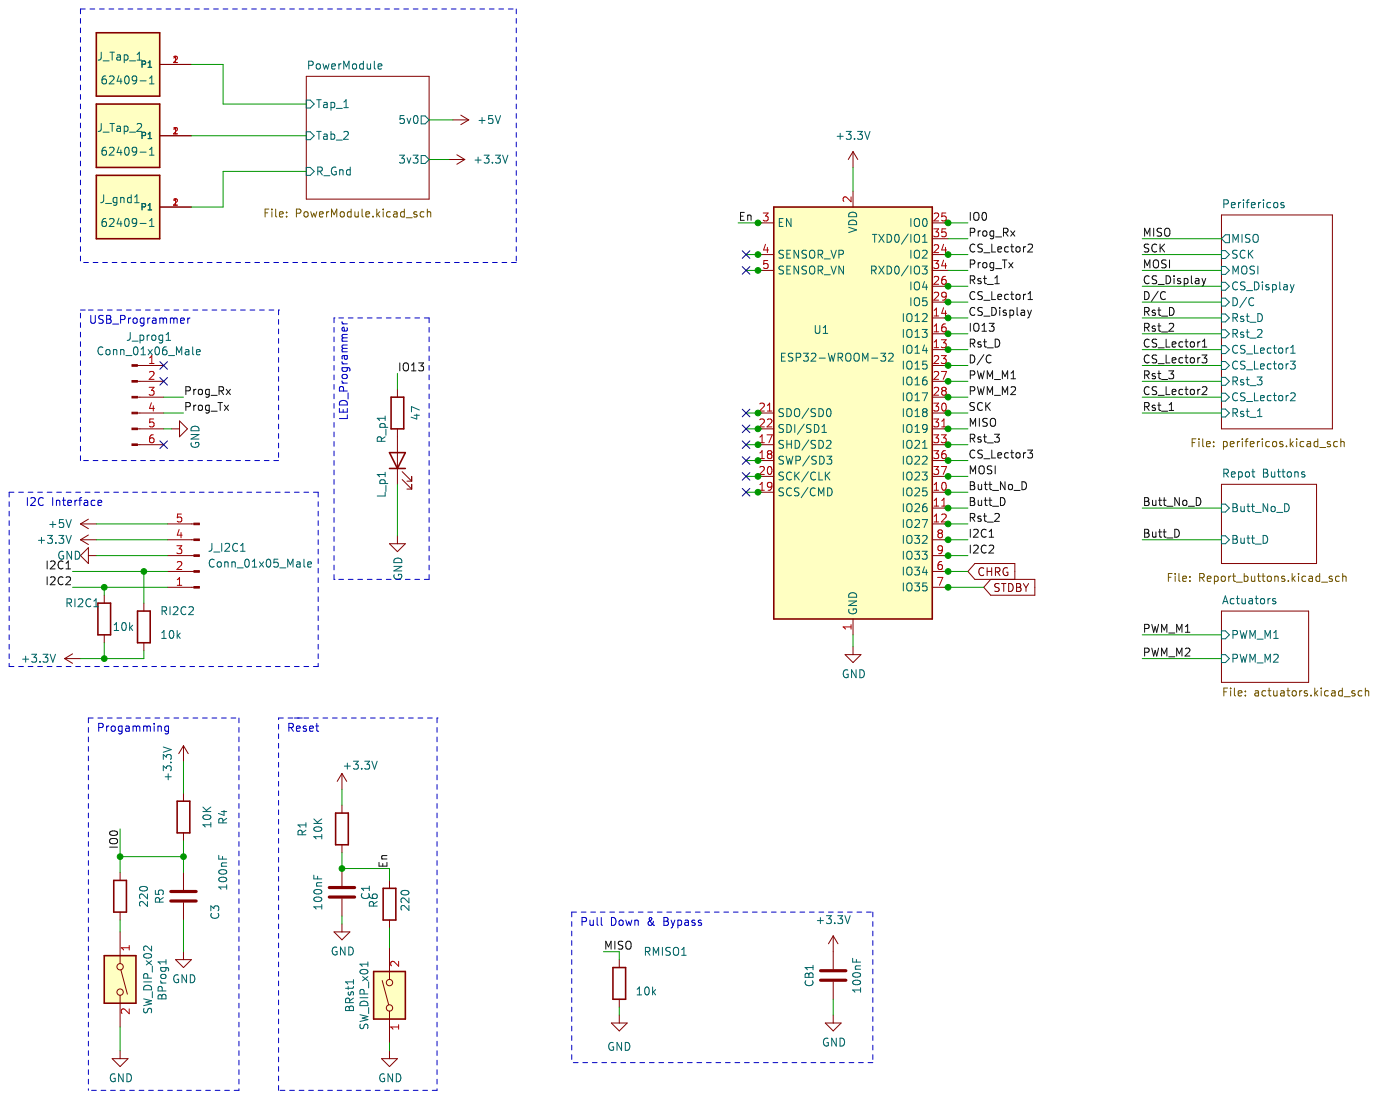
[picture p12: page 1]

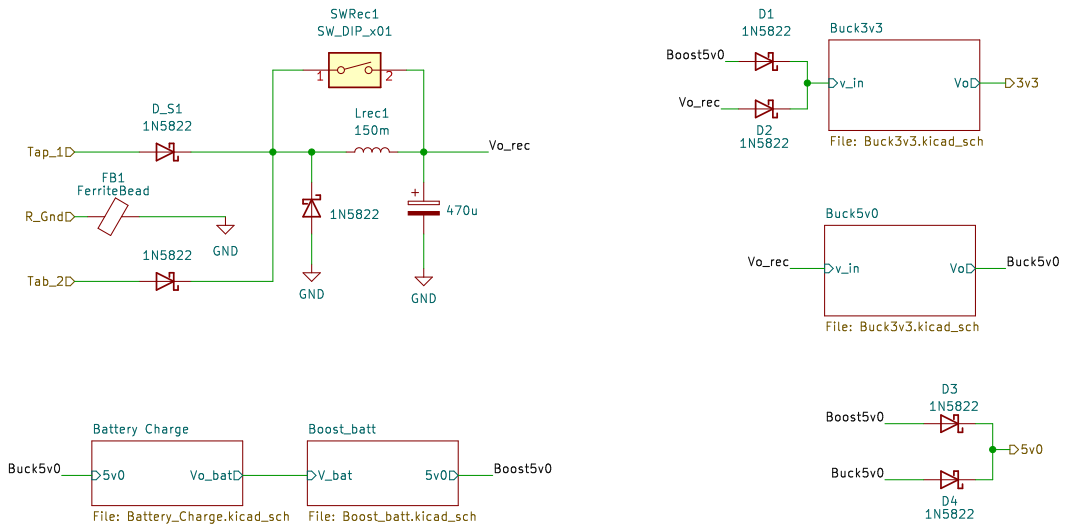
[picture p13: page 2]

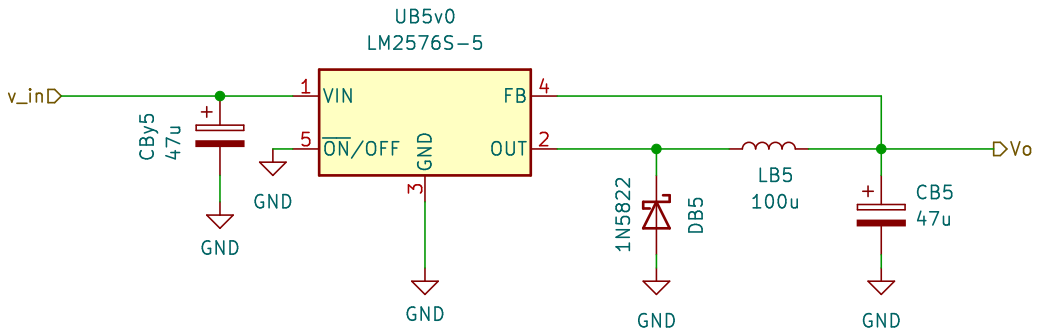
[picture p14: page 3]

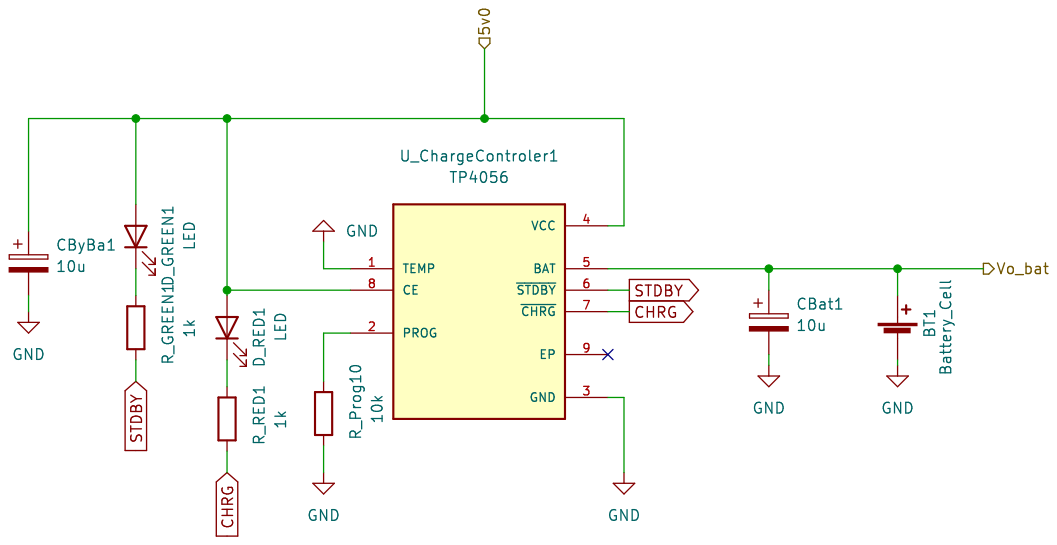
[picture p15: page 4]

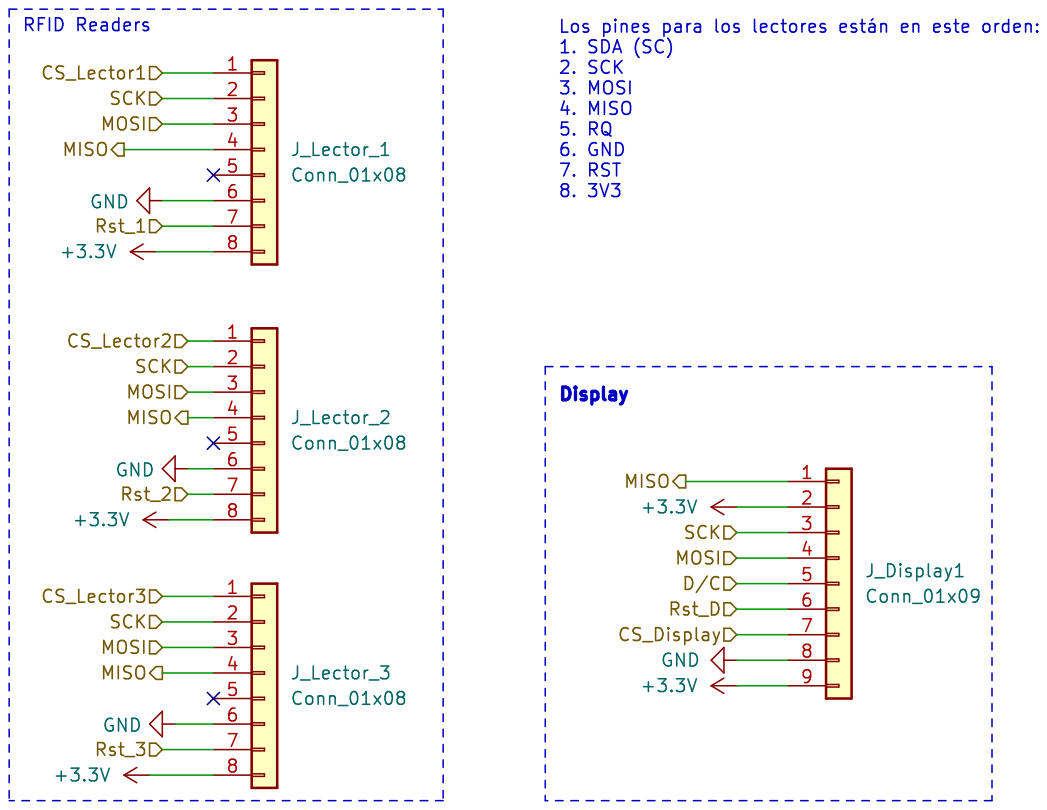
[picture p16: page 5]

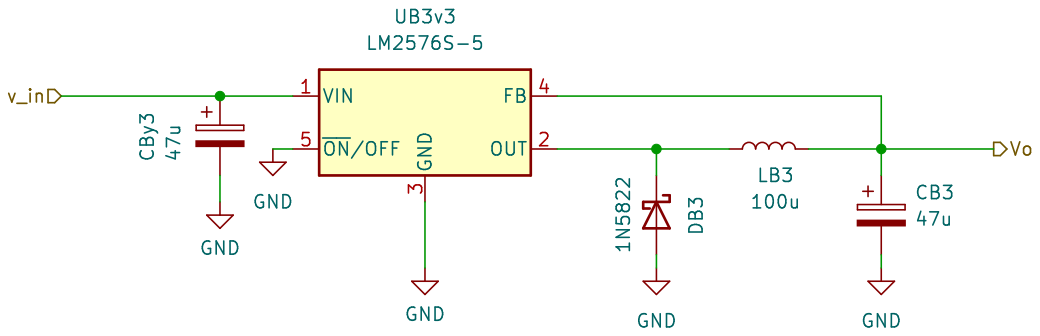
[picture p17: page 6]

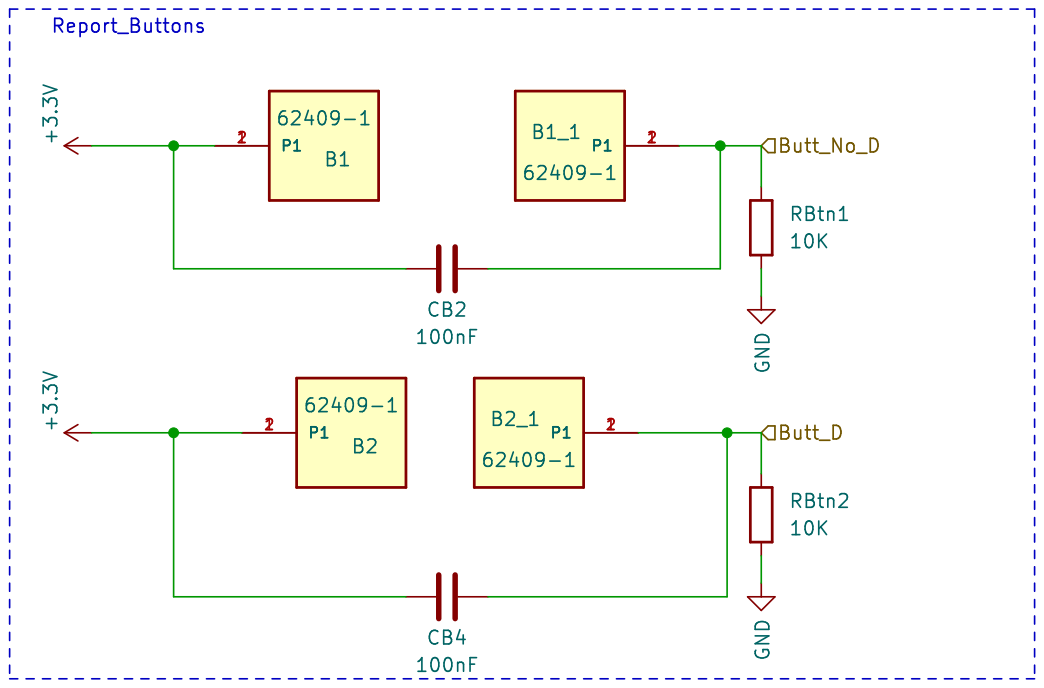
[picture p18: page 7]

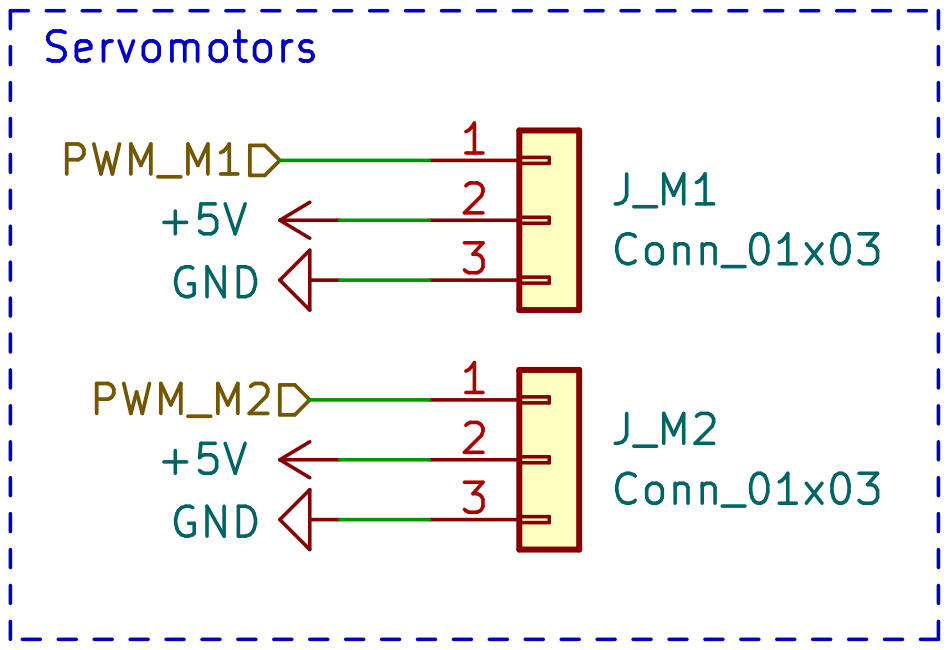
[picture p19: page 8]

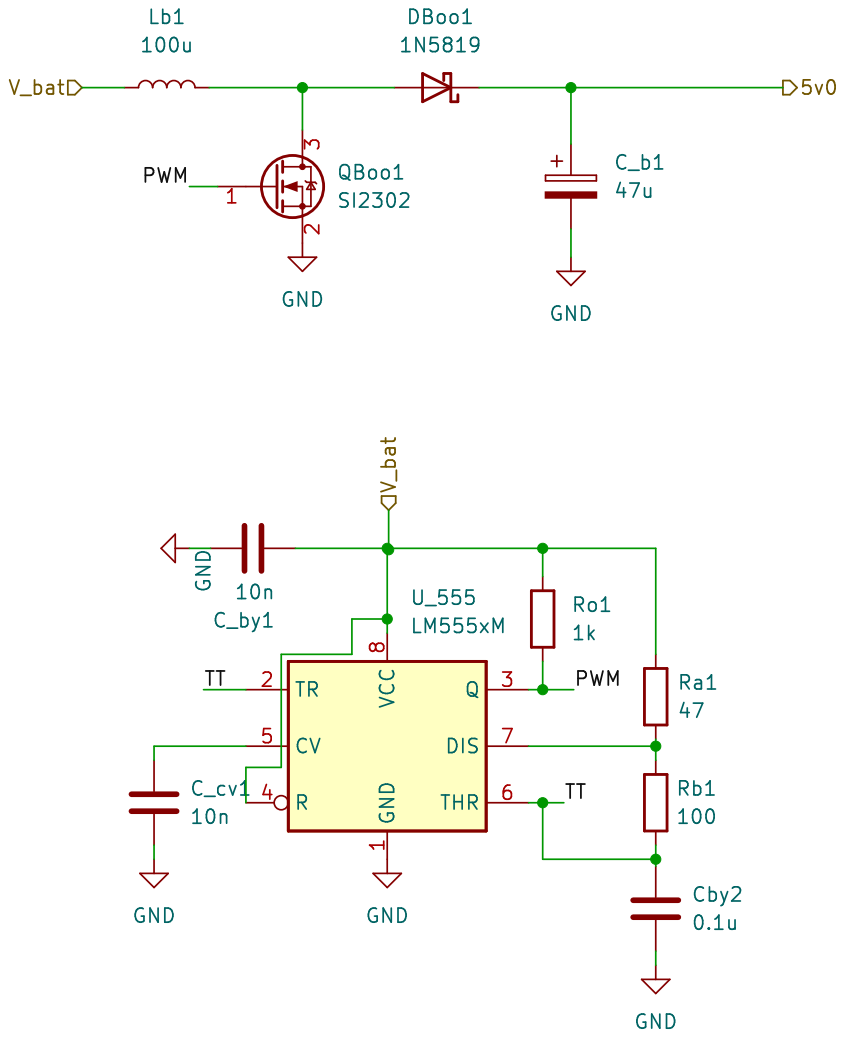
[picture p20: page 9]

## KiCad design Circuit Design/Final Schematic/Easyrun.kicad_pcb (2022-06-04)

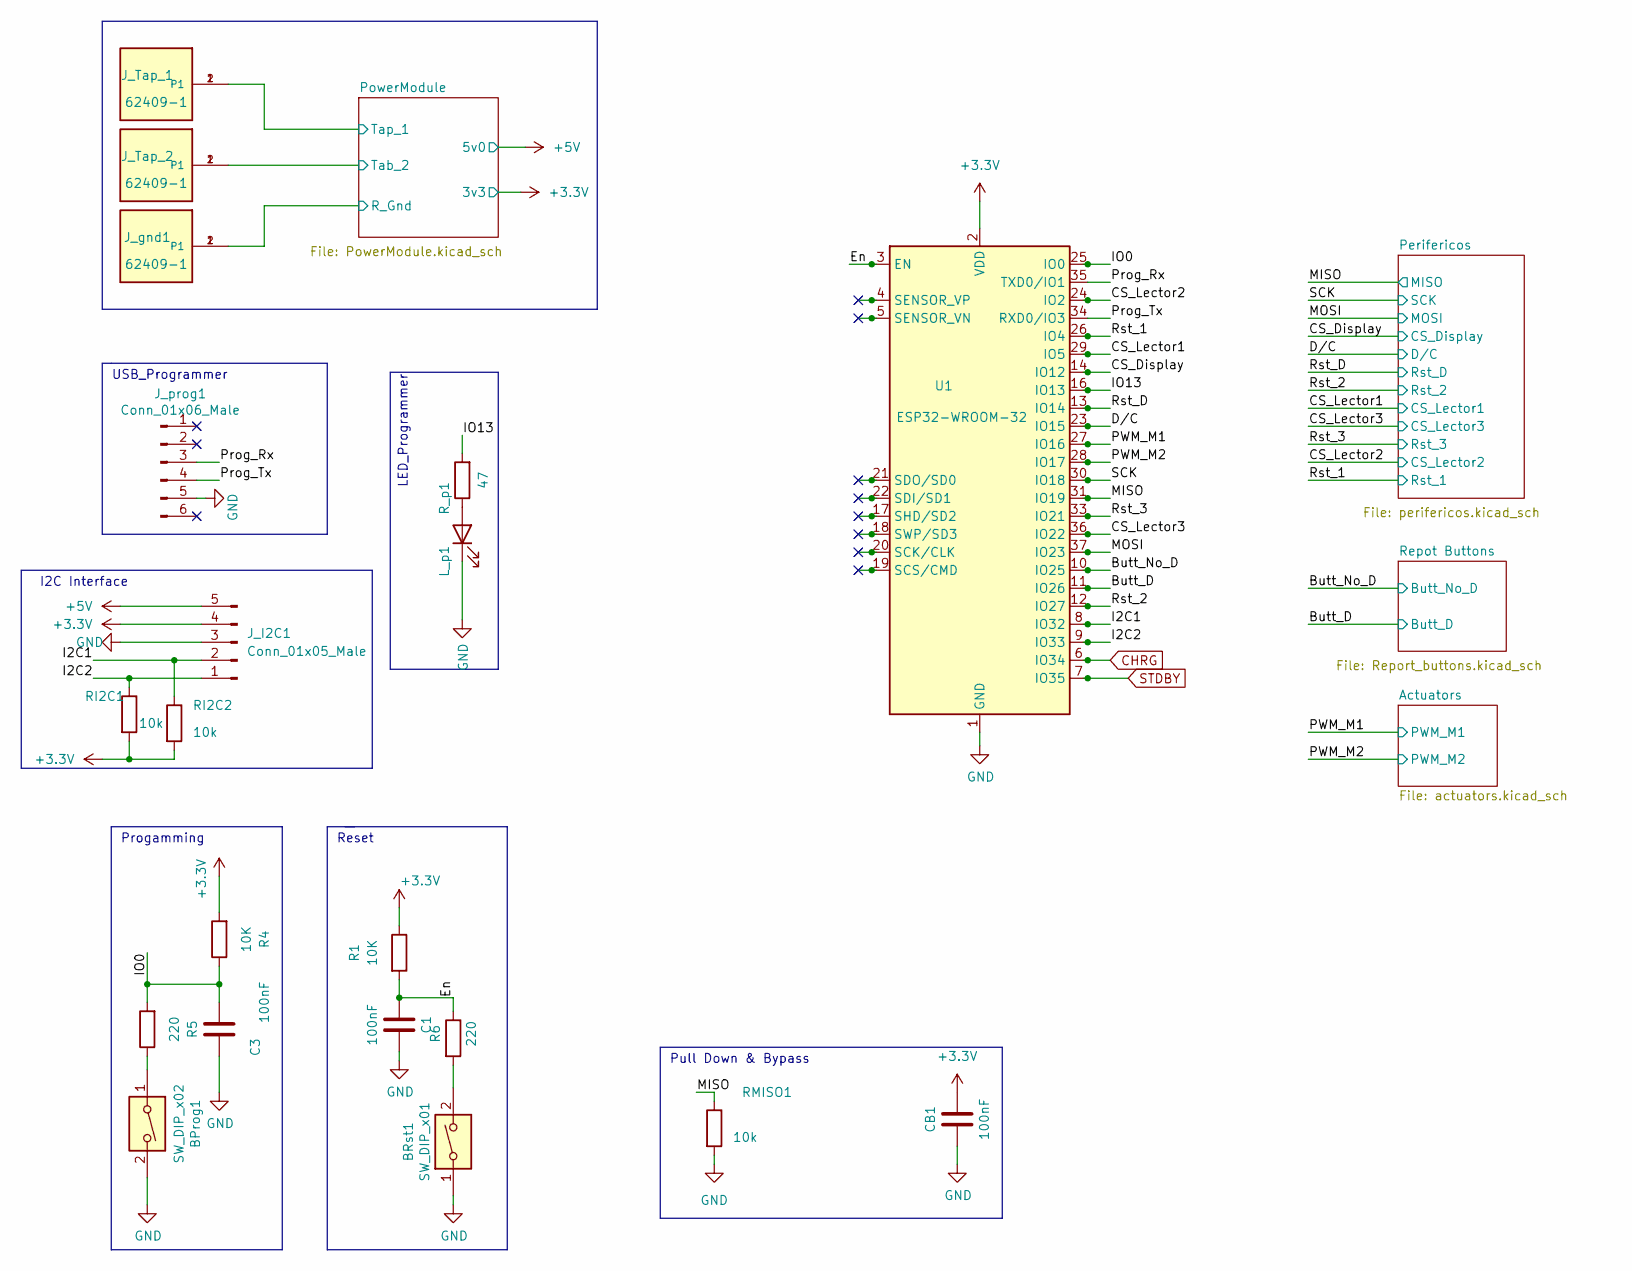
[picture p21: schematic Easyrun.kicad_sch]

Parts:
BProg1: SW_DIP_x02; SW_SPST_CK_RS282G05A3
BRst1: SW_DIP_x01; SW_SPST_CK_RS282G05A3
C1, C3: 100nF; C_0805_2012Metric_Pad1.18x1.45mm_HandSolder
CB1: 100nF; C_0805_2012Metric_Pad1.18x1.45mm_HandSolder
J_I2C1: Conn_01x05_Male; PinSocket_1x05_P2.54mm_Horizontal
J_Tap_1, J_Tap_2: 62409-1; TE_62409-1
J_gnd1: 62409-1; TE_62409-1
J_prog1: Conn_01x06_Male; PinHeader_1x06_P2.54mm_Horizontal
L_p1: LED; LED_0805_2012Metric_Pad1.15x1.40mm_HandSolder
R1, R4: 10K; R_0805_2012Metric_Pad1.20x1.40mm_HandSolder
R5, R6: 220; R_0805_2012Metric_Pad1.20x1.40mm_HandSolder
RI2C1, RI2C2: 10k; R_0805_2012Metric_Pad1.20x1.40mm_HandSolder
RMISO1: 10k; R_0805_2012Metric_Pad1.20x1.40mm_HandSolder
R_p1: 47; R_0805_2012Metric_Pad1.20x1.40mm_HandSolder
U1: ESP32-WROOM-32

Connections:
+3V3: CB1.1, J_I2C1.4, R1.1, R4.2, RI2C1.2, RI2C2.2, U1.2 (VDD); also elsewhere on the board
+5V: J_I2C1.5; also elsewhere on the board
/Butt_D: U1.11 (IO26); also elsewhere on the board
/Butt_No_D: U1.10 (IO25); also elsewhere on the board
/CS_Display: U1.14 (IO12); also elsewhere on the board
/CS_Lector1: U1.29 (IO5); also elsewhere on the board
/CS_Lector2: U1.24 (IO2); also elsewhere on the board
/CS_Lector3: U1.36 (IO22); also elsewhere on the board
/D/C: U1.23 (IO15); also elsewhere on the board
/En: C1.2, R1.2, R6.1, U1.3 (EN)
/I2C1: J_I2C1.2, RI2C2.1, U1.8 (IO32)
/I2C2: J_I2C1.1, RI2C1.1, U1.9 (IO33)
/IO0: C3.1, R4.1, R5.2, U1.25 (IO0)
/IO13: R_p1.2, U1.16 (IO13)
/MISO: RMISO1.1, U1.31 (IO19); also elsewhere on the board
/MOSI: U1.37 (IO23); also elsewhere on the board
/PWM_M1: U1.27 (IO16); also elsewhere on the board
/PWM_M2: U1.28 (IO17); also elsewhere on the board
/PowerModule/R_Gnd: J_gnd1.1, J_gnd1.2 (P1); also elsewhere on the board
/PowerModule/Tab_2: J_Tap_2.1, J_Tap_2.2 (P1); also elsewhere on the board
/PowerModule/Tap_1: J_Tap_1.1, J_Tap_1.2 (P1); also elsewhere on the board
/Prog_Rx: J_prog1.3, U1.35 (TXD0/IO1)
/Prog_Tx: J_prog1.4, U1.34 (RXD0/IO3)
/Rst_1: U1.26 (IO4); also elsewhere on the board
/Rst_2: U1.12 (IO27); also elsewhere on the board
/Rst_3: U1.33 (IO21); also elsewhere on the board
/Rst_D: U1.13 (IO14); also elsewhere on the board
/SCK: U1.30 (IO18); also elsewhere on the board
CHRG: U1.6 (IO34); also elsewhere on the board
GND: BProg1.2, BRst1.1, C1.1, C3.2, CB1.2, J_I2C1.3, J_prog1.5, L_p1.1 (K), RMISO1.2, U1.1 (GND), U1.15 (GND), U1.38 (GND), U1.39 (GND); also elsewhere on the board
unnamed: BProg1.1, R5.1
unnamed: BRst1.2, R6.2
unnamed: L_p1.2 (A), R_p1.1
STDBY: U1.7 (IO35); also elsewhere on the board

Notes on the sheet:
LED_Programmer
I2C Interface
Progamming
Pull Down & Bypass
Reset
USB_Programmer

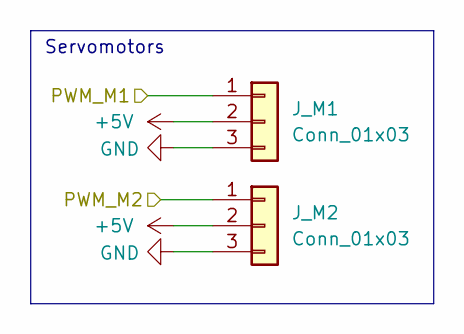
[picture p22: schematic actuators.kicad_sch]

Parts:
J_M1, J_M2: Conn_01x03; JST_EH_S3B-EH_1x03_P2.50mm_Horizontal

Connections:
+5V: J_M1.2, J_M2.2; also elsewhere on the board
/PWM_M1: J_M1.1; also elsewhere on the board
/PWM_M2: J_M2.1; also elsewhere on the board
GND: J_M1.3, J_M2.3; also elsewhere on the board

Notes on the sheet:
Servomotors

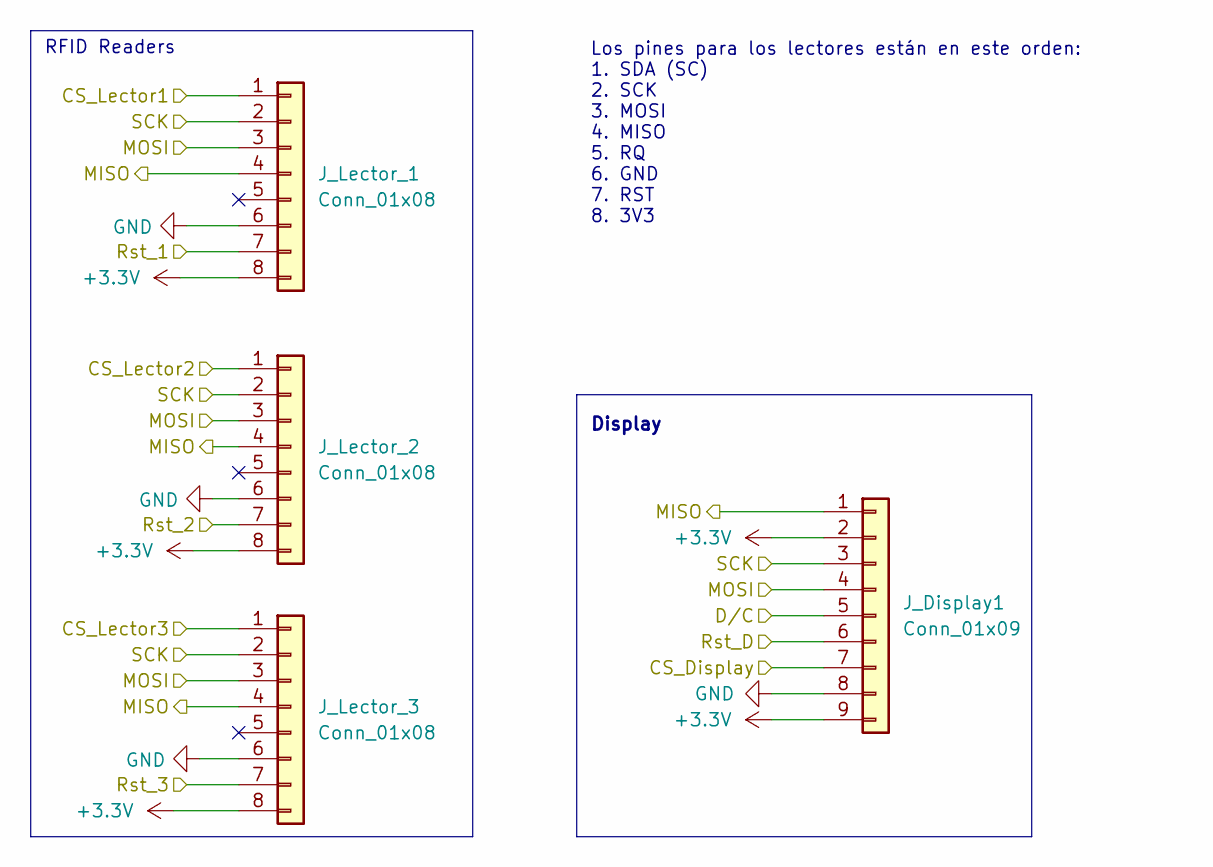
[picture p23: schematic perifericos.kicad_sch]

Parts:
J_Display1: Conn_01x09; JST_EH_S9B-EH_1x09_P2.50mm_Horizontal
J_Lector_1, J_Lector_2, J_Lector_3: Conn_01x08; JST_EH_S8B-EH_1x08_P2.50mm_Horizontal

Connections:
+3V3: J_Display1.2, J_Display1.9, J_Lector_1.8, J_Lector_2.8, J_Lector_3.8; also elsewhere on the board
/CS_Display: J_Display1.7; also elsewhere on the board
/CS_Lector1: J_Lector_1.1; also elsewhere on the board
/CS_Lector2: J_Lector_2.1; also elsewhere on the board
/CS_Lector3: J_Lector_3.1; also elsewhere on the board
/D/C: J_Display1.5; also elsewhere on the board
/MISO: J_Display1.1, J_Lector_1.4, J_Lector_2.4, J_Lector_3.4; also elsewhere on the board
/MOSI: J_Display1.4, J_Lector_1.3, J_Lector_2.3, J_Lector_3.3; also elsewhere on the board
/Rst_1: J_Lector_1.7; also elsewhere on the board
/Rst_2: J_Lector_2.7; also elsewhere on the board
/Rst_3: J_Lector_3.7; also elsewhere on the board
/Rst_D: J_Display1.6; also elsewhere on the board
/SCK: J_Display1.3, J_Lector_1.2, J_Lector_2.2, J_Lector_3.2; also elsewhere on the board
GND: J_Display1.8, J_Lector_1.6, J_Lector_2.6, J_Lector_3.6; also elsewhere on the board

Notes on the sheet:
RFID Readers
Display
Los pines para los lectores están en este orden: 1. SDA (SC) 2. SCK 3. MOSI 4. MISO 5. RQ 6. GND 7. RST 8. 3V3

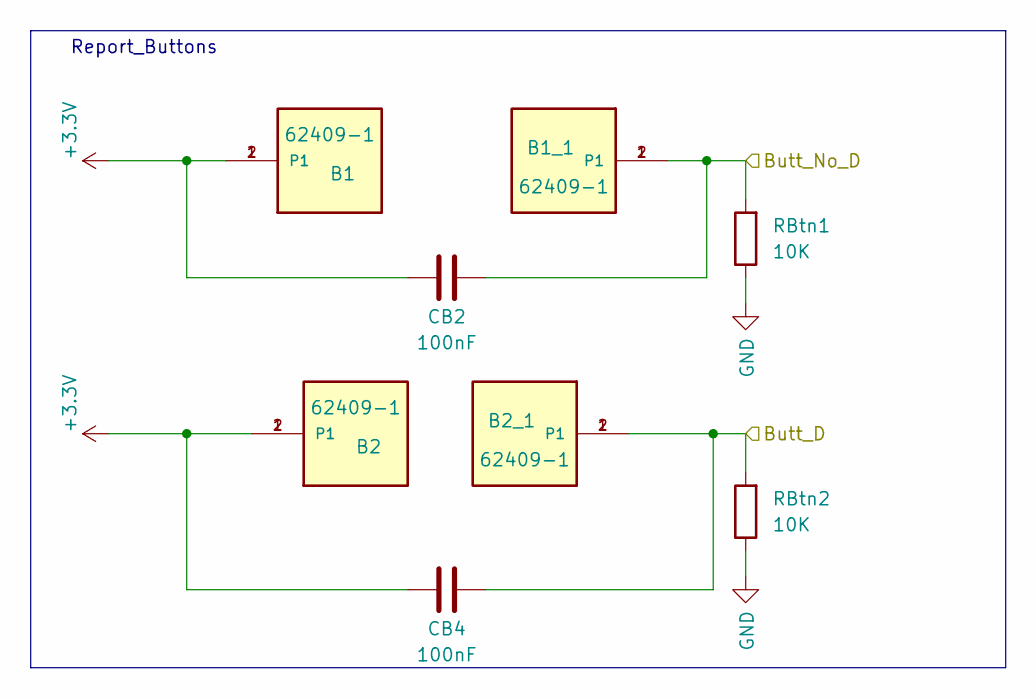
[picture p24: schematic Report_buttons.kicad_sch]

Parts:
B1, B1_1, B2, B2_1: 62409-1; TE_62409-1
CB2, CB4: 100nF; C_0805_2012Metric_Pad1.18x1.45mm_HandSolder
RBtn1, RBtn2: 10K; R_0805_2012Metric_Pad1.20x1.40mm_HandSolder

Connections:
+3V3: B1.1, B1.2 (P1), B2.1, B2.2 (P1), CB2.1, CB4.1; also elsewhere on the board
/Butt_D: B2_1.1, B2_1.2 (P1), CB4.2, RBtn2.2; also elsewhere on the board
/Butt_No_D: B1_1.1, B1_1.2 (P1), CB2.2, RBtn1.2; also elsewhere on the board
GND: RBtn1.1, RBtn2.1; also elsewhere on the board

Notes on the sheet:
Report_Buttons

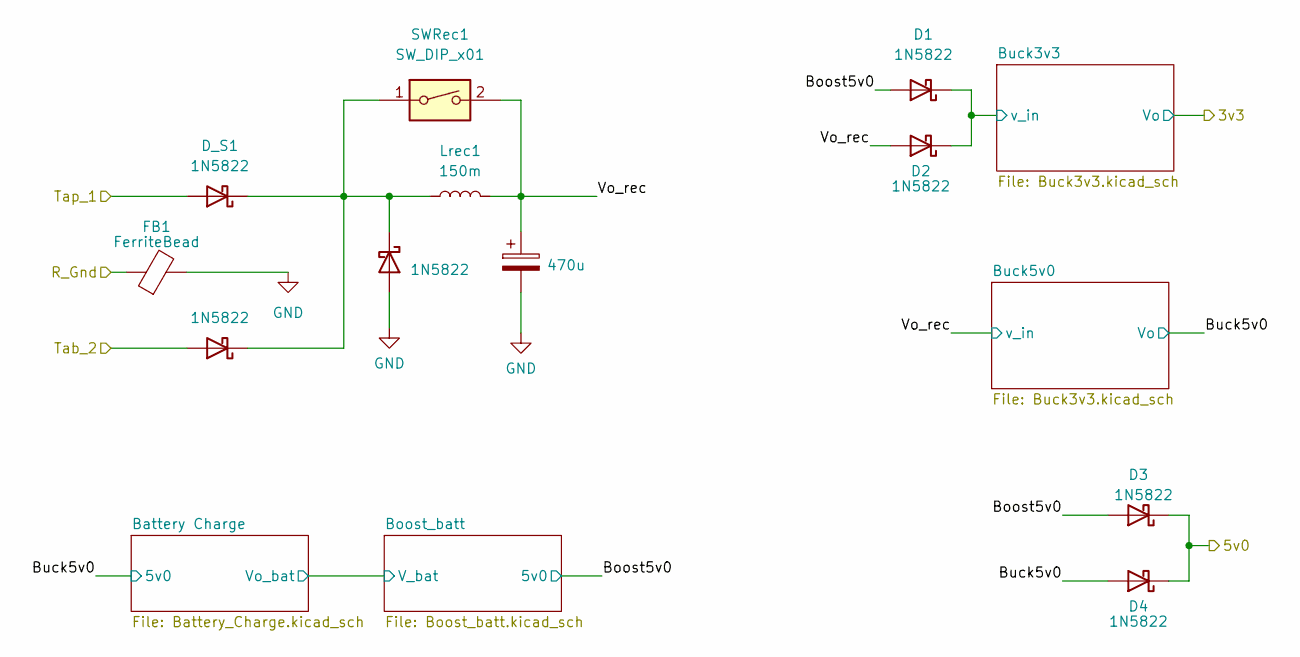
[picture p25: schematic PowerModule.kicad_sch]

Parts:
Crec1: 470u; CP_Radial_D6.3mm_P2.50mm
D1, D2, D3, D4: 1N5822; D_DO-201AE_P5.08mm_Vertical_AnodeUp
DFly1: 1N5822; D_DO-201AE_P5.08mm_Vertical_AnodeUp
D_S1, D_S2: 1N5822; D_DO-201AE_P5.08mm_Vertical_AnodeUp
FB1: FerriteBead; R_1812_4532Metric_Pad1.30x3.40mm_HandSolder
Lrec1: 150m; L_Toroid_Vertical_L25.4mm_W14.7mm_P12.20mm_Vishay_TJ5_BigPa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
SWRec1: SW_DIP_x01; PinHeader_1x02_P2.54mm_Vertical_SMD_Pin1Left

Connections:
+5V: D3.1 (K), D4.1 (K); also elsewhere on the board
/PowerModule/Boost5v0: D1.2 (A), D3.2 (A); also elsewhere on the board
/PowerModule/Buck3v3/v_in: D1.1 (K), D2.1 (K); also elsewhere on the board
/PowerModule/Buck5v0: D4.2 (A); also elsewhere on the board
/PowerModule/R_Gnd: FB1.1; also elsewhere on the board
/PowerModule/Tab_2: D_S2.2 (A); also elsewhere on the board
/PowerModule/Tap_1: D_S1.2 (A); also elsewhere on the board
/PowerModule/Vo_rec: Crec1.1, D2.2 (A), Lrec1.2, SWRec1.2; also elsewhere on the board
GND: Crec1.2, DFly1.2 (A), FB1.2; also elsewhere on the board
unnamed: DFly1.1 (K), D_S1.1 (K), D_S2.1 (K), Lrec1.1, SWRec1.1

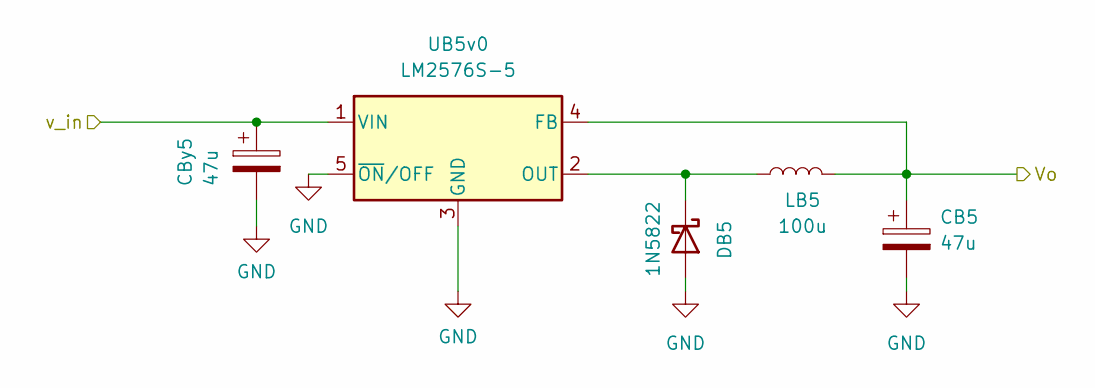
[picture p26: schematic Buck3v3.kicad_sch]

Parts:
CB5: 47u; CP_Elec_6.3x5.8
CBy5: 47u; CP_EIA-7343-43_Kemet-X_Pad2.25x2.55mm_HandSolder
DB5: 1N5822; D_DO-201AE_P5.08mm_Vertical_AnodeUp
LB5: 100u; L_Toroid_Vertical_L25.4mm_W14.7mm_P12.20mm_Vishay_TJ5_BigPa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
UB5v0: LM2576S-5; TO-263-5_TabPin3

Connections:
/PowerModule/Buck5v0: CB5.1, LB5.2, UB5v0.4 (FB); also elsewhere on the board
/PowerModule/Vo_rec: CBy5.1, UB5v0.1 (VIN); also elsewhere on the board
GND: CB5.2, CBy5.2, DB5.2 (A), UB5v0.3 (GND), UB5v0.5 (~ON/OFF); also elsewhere on the board
unnamed: DB5.1 (K), LB5.1, UB5v0.2 (OUT)

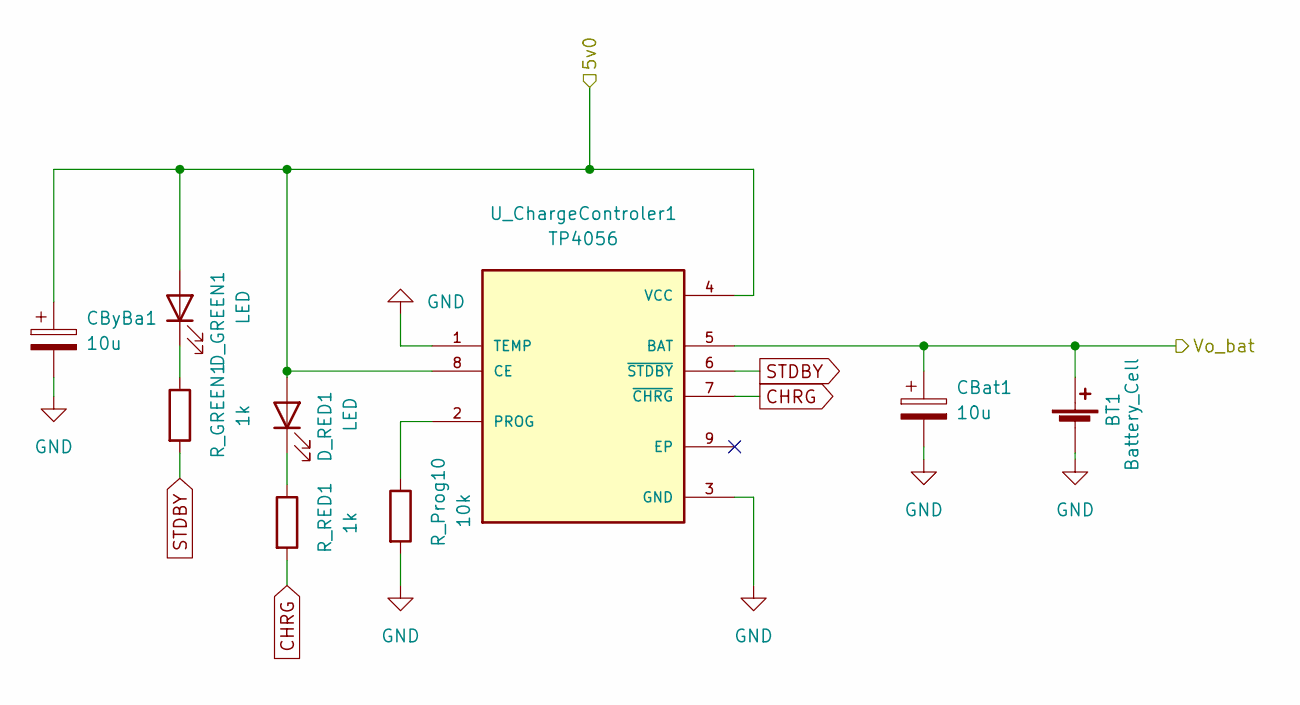
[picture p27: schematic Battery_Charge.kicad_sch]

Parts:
BT1: Battery_Cell; BatteryHolder_MPD_BH-18650-PC2
CBat1: 10u; CP_Elec_6.3x5.8
CByBa1: 10u; CP_Elec_6.3x5.8
D_GREEN1: LED; LED_0805_2012Metric_Pad1.15x1.40mm_HandSolder
D_RED1: LED; LED_0805_2012Metric_Pad1.15x1.40mm_HandSolder
R_GREEN1: 1k; R_0805_2012Metric_Pad1.20x1.40mm_HandSolder
R_Prog10: 10k; R_0805_2012Metric_Pad1.20x1.40mm_HandSolder
R_RED1: 1k; R_0805_2012Metric_Pad1.20x1.40mm_HandSolder
U_ChargeControler1: TP4056; SOP127P600X175-9N

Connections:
/PowerModule/Battery Charge/Vo_bat: BT1.1 (+), CBat1.1, U_ChargeControler1.5 (BAT); also elsewhere on the board
/PowerModule/Buck5v0: CByBa1.1, D_GREEN1.2 (A), D_RED1.2 (A), U_ChargeControler1.4 (VCC), U_ChargeControler1.8 (CE); also elsewhere on the board
CHRG: R_RED1.2, U_ChargeControler1.7 (~CHRG); also elsewhere on the board
GND: BT1.2 (-), CBat1.2, CByBa1.2, R_Prog10.2, U_ChargeControler1.1 (TEMP), U_ChargeControler1.3 (GND); also elsewhere on the board
unnamed: D_GREEN1.1 (K), R_GREEN1.1
unnamed: D_RED1.1 (K), R_RED1.1
unnamed: R_Prog10.1, U_ChargeControler1.2 (PROG)
STDBY: R_GREEN1.2, U_ChargeControler1.6 (~STDBY); also elsewhere on the board

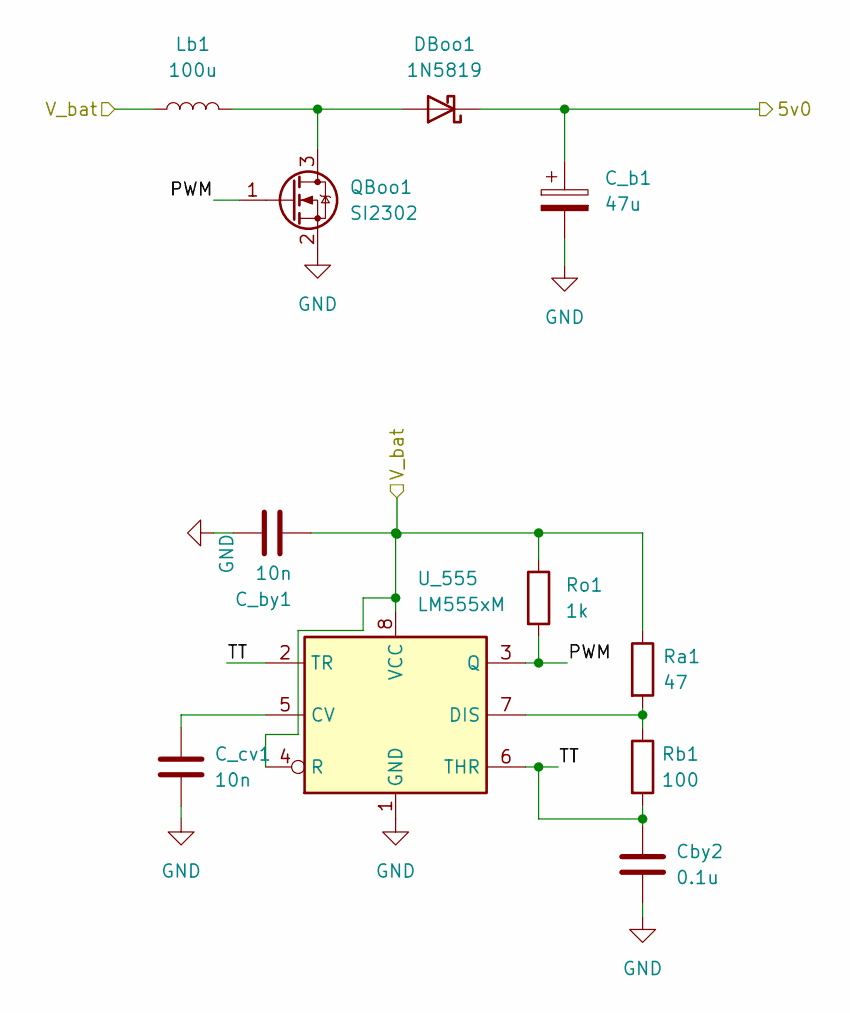
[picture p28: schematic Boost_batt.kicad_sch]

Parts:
C_b1: 47u; CP_Elec_6.3x5.8
C_by1: 10n; C_0805_2012Metric_Pad1.18x1.45mm_HandSolder
C_cv1: 10n; C_0805_2012Metric_Pad1.18x1.45mm_HandSolder
Cby2: 0.1u; C_0805_2012Metric_Pad1.18x1.45mm_HandSolder
DBoo1: 1N5819; D_DO-201AE_P5.08mm_Vertical_AnodeUp
Lb1: 100u; L_Toroid_Vertical_L25.4mm_W14.7mm_P12.20mm_Vishay_TJ5_BigPa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
QBoo1: SI2302; SOT-23
Ra1: 47; R_0805_2012Metric_Pad1.20x1.40mm_HandSolder
Rb1: 100; R_0805_2012Metric_Pad1.20x1.40mm_HandSolder
Ro1: 1k; R_0805_2012Metric_Pad1.20x1.40mm_HandSolder
U_555: LM555xM; SOIC-8_3.9x4.9mm_P1.27mm

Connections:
/PowerModule/Battery Charge/Vo_bat: Lb1.1; also elsewhere on the board
/PowerModule/Boost5v0: C_b1.1, DBoo1.1 (K); also elsewhere on the board
/PowerModule/Boost_batt/PWM: QBoo1.1 (G), Ro1.2, U_555.3 (Q)
/PowerModule/Boost_batt/TT: Cby2.1, Rb1.2, U_555.2 (TR), U_555.6 (THR)
GND: C_b1.2, C_by1.1, C_cv1.2, Cby2.2, QBoo1.2 (S), U_555.1 (GND); also elsewhere on the board
unnamed: C_by1.2, Ra1.1, Ro1.1, U_555.4 (R), U_555.8 (VCC)
unnamed: C_cv1.1, U_555.5 (CV)
unnamed: DBoo1.2 (A), Lb1.2, QBoo1.3 (D)
unnamed: Ra1.2, Rb1.1, U_555.7 (DIS)

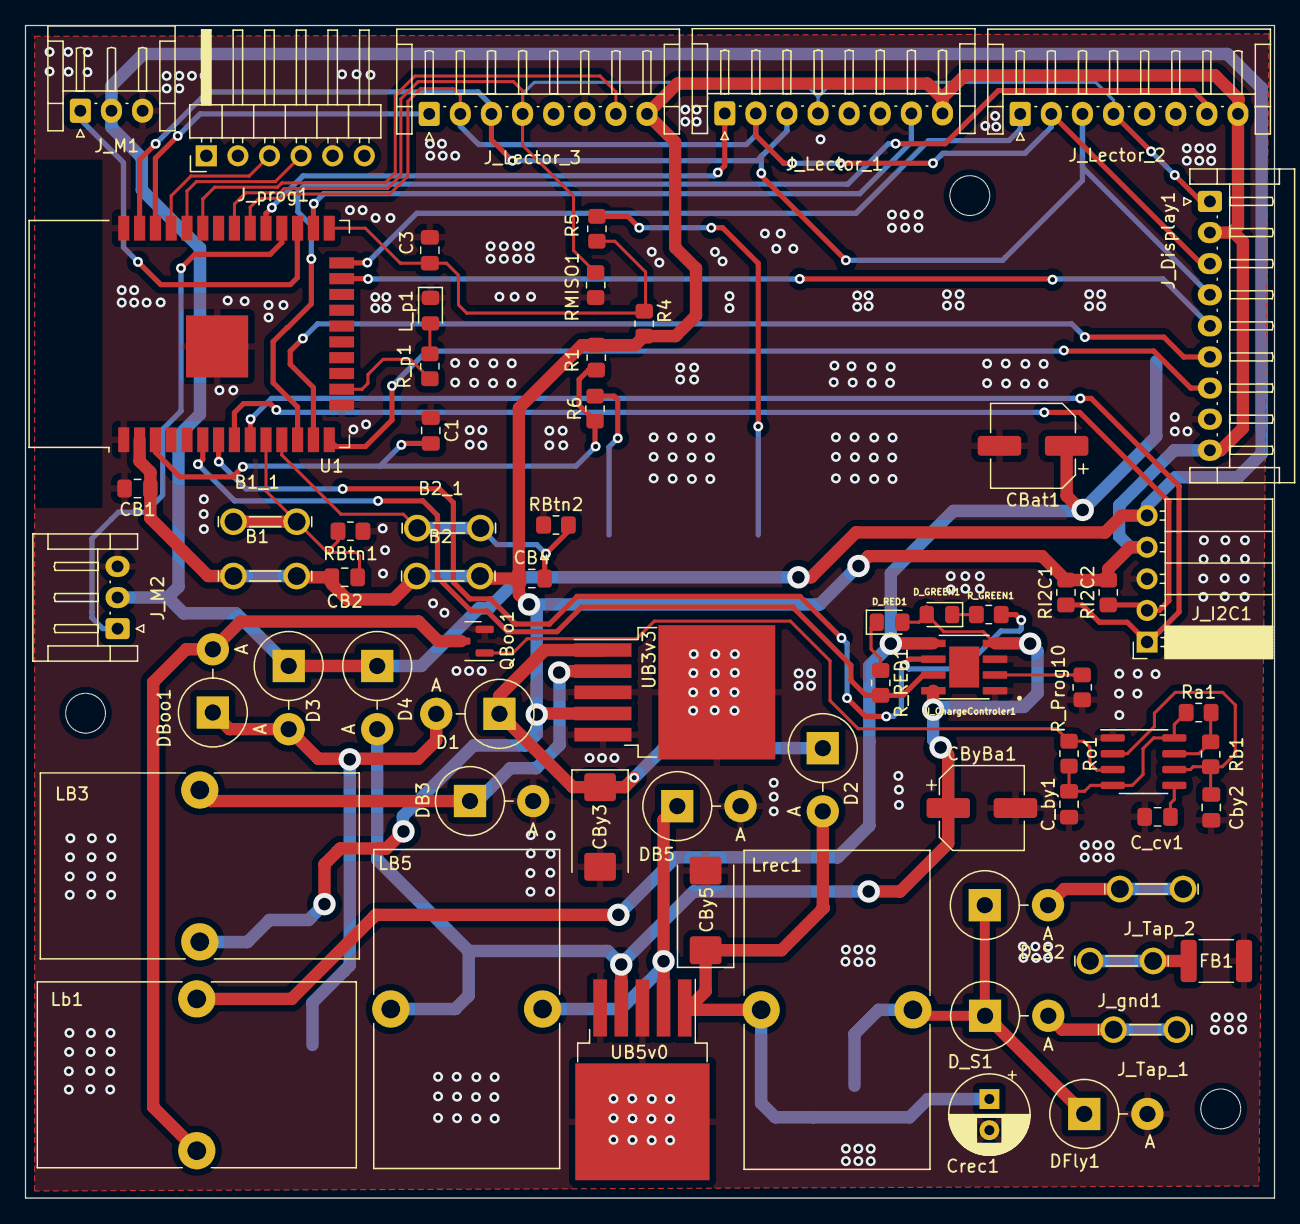
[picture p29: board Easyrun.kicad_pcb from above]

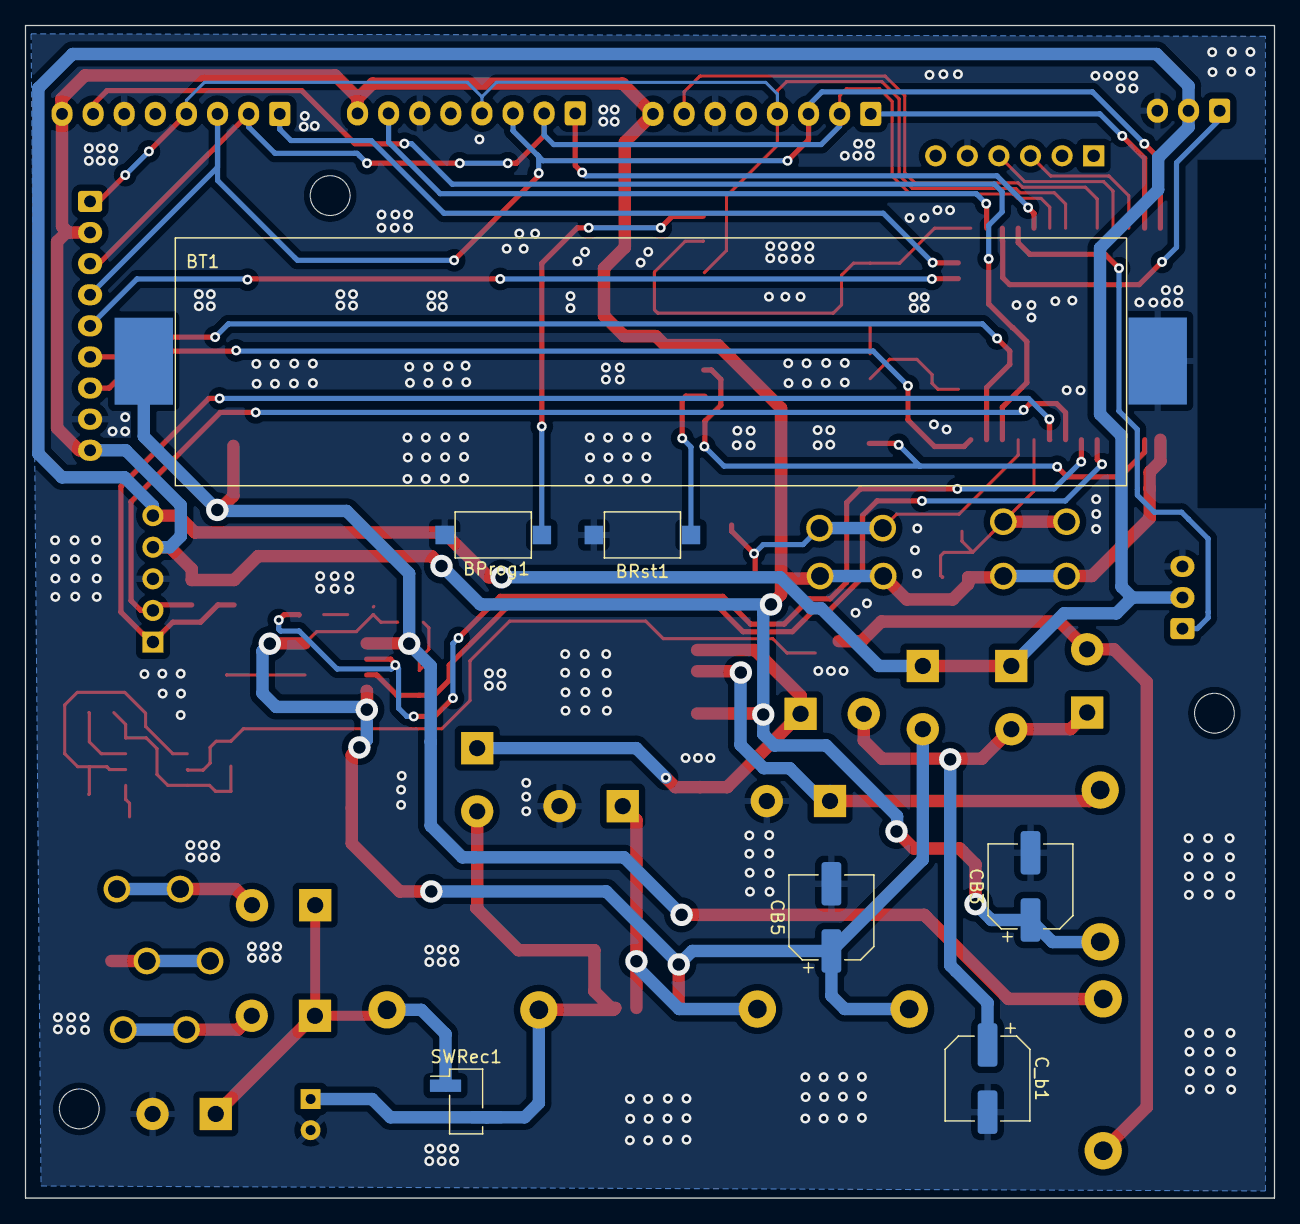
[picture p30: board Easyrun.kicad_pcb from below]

Board: 2 copper layers, 100.4 x 94.2 mm, 75 parts (7 on the bottom side), 51 nets.

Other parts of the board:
CB3: 47u; CP_Elec_6.3x5.8
CBy3: 47u; CP_EIA-7343-43_Kemet-X_Pad2.25x2.55mm_HandSolder
DB3: 1N5822; D_DO-201AE_P5.08mm_Vertical_AnodeUp
LB3: 100u; L_Toroid_Vertical_L25.4mm_W14.7mm_P12.20mm_Vishay_TJ5_BigPa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
UB3v3: LM2576S-5; TO-263-5_TabPin3

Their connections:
+3V3: CB3.1, LB3.2, UB3v3.4 (FB); also elsewhere on the board
/PowerModule/Buck3v3/v_in: CBy3.1, UB3v3.1 (VIN); also elsewhere on the board
GND: CB3.2, CBy3.2, DB3.2 (A), UB3v3.3 (GND), UB3v3.5 (~ON/OFF); also elsewhere on the board
unnamed: DB3.1 (K), LB3.1, UB3v3.2 (OUT)

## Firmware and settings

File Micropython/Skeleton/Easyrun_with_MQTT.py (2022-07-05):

import Perifericos
import json
import machine
from Clases_Easyrun import Bicicleta, Candado, Persona
from ili9341 import Display, color565
from machine import Pin, SPI, PWM
from xglcd_font import XglcdFont
from machine import SoftSPI
from displayLib import MyDisplay
from Messages import *
from MQTTconnection import *

import math
import time



Puesto_de_prestamo = 'CyT'
#Puesto_de_prestamo = '30'

disp=MyDisplay(Perifericos.get_spi())

Persona_1 = Persona()
Persona_2 = Persona()

Bicicleta_1 = Bicicleta()
Bicicleta_2 = Bicicleta()

Candado_1 = Candado()
Candado_2 = Candado()

Bicicleta_1.candado = Candado_1
Bicicleta_2.candado = Candado_2
Bicicleta_1.persona = Persona_1
Bicicleta_2.persona = Persona_2


Bike_avail = [Bicicleta_1, Bicicleta_2]

# MQTT
client_id = "ESP32_Easyrun"
last_message = 0
send = True
#conect_to("Juan F","qwertyuiop")
conect_to("Omega-9523","12345678")
try:
  client = connect_and_subscribe()
except OSError as e:
  restart_and_reconnect()

client.publish(b'SI/Validate',send_id(client_id, "0"),True,1)
time.sleep(1)
client.check_msg()
msg_received= msgFromSI()

for i in range(0, len(Bike_avail)):
    Bike_avail[i].candado.ubicacion = 'CyT'
    Bike_avail[i].candado.n_candado = i+1


timer_1 = machine.Timer(0)
timer_2 = machine.Timer(0)

Bicicleta_entrega = 0
interruptCounter_1 = 0

def Reporte_bike_1(pin):
    Bike_avail[0].danos = True # No dañada = False/ Dañada = True
    Bike_avail[0].estado = False
    client.publish(b'Easyrun/GetBack',
            getBack(client_id, Bike_avail[0].iD, Bike_avail[0].candado.ubicacion,
                Bike_avail[0].danos),True,1)
    # with open('Devolucion_auto.json') as Devolucion:
    #         data_send_devolucion = json.load(Devolucion)
    #         data_send_devolucion['id_bike'] = Bike_avail[0].iD
    #         data_send_devolucion['danos'] = Bike_avail[0].danos
    #         data_send_devolucion['punto_de_prestamo'] = Bike_avail[0].candado.ubicacion
    #         #### Enviar data_send_devolucion de carnet al SI, hacer un while para esperar confirmacion
    print("Esto es una interrupcion externa")

Danos_Bike_1 = machine.Pin(25, machine.Pin.IN, machine.Pin.PULL_DOWN)
Danos_Bike_1.irq(trigger=machine.Pin.IRQ_FALLING, handler=Reporte_bike_1)

def Reporte_bike_2(pin):
    Bike_avail[1].danos = True # No dañada = False/ Dañada = True
    Bike_avail[1].estado = False
    client.publish(b'Easyrun/GetBack',
            getBack(client_id, Bike_avail[1].iD, Bike_avail[1].candado.ubicacion,
                Bike_avail[1].danos),True,1)
    # with open('Devolucion_auto.json') as Devolucion:
    #         data_send_devolucion = json.load(Devolucion)
    #         data_send_devolucion['id_bike'] = Bike_avail[1].iD
    #         data_send_devolucion['danos'] = Bike_avail[1].danos
    #         data_send_devolucion['punto_de_prestamo'] = Bike_avail[1].candado.ubicacion
    #         #### Enviar data_send_devolucion de carnet al SI, hacer un while para esperar confirmacion
    print("Esto es una interrupcion externa_B2")

Danos_Bike_2 = machine.Pin(26, machine.Pin.IN, machine.Pin.PULL_DOWN)
Danos_Bike_2.irq(trigger=machine.Pin.IRQ_FALLING, handler=Reporte_bike_2)


def Interrupt_T1(timer_1):
    print("interrupcion")
    global interruptCounter_1
    interruptCounter_1 = interruptCounter_1 + 1
    card_id_Bike_interr_1 = Perifericos.lectura(Bicicleta_entrega+2)
    print("Detectada aun Bicicleta para prestamo",card_id_Bike_interr_1)
    if(card_id_Bike_interr_1 == None):
        timer_1.deinit()
        Bike_avail[Bicicleta_entrega].candado.estado = 'vacio'
        interruptCounter_1 = 0
        print("Se llevaron la cicla sumercé")
        client.publish(b'Easyrun/Borrow',
            borrow(client_id, str(Bike_avail[Bicicleta_entrega].persona.cedula),
                Bike_avail[Bicicleta_entrega].iD,
                Bike_avail[Bicicleta_entrega].candado.ubicacion),True,1)
        # with open('Prestamo_normal.json') as Prestamo_normal:
        #     data_send_prestamo_normal = json.load(Prestamo_normal)
        #     data_send_prestamo_normal['id_bike'] = Bike_avail[Bicicleta_entrega].iD
        #     data_send_prestamo_normal['cedula'] = Bike_avail[Bicicleta_entrega].persona.cedula
        #     #### Enviar data_send_prestamo_normal de carnet al SI, hacer un while para esperar confirmacion de receprcion
        Bike_avail[Bicicleta_entrega].persona.reset()

    if(interruptCounter_1>=3):
        Perifericos.servo_close(Bicicleta_entrega+1)
        interruptCounter_1 = 0
        client.publish(b'Easyrun/GetBack',
            getBack(client_id, Bike_avail[Bicicleta_entrega].iD, Bike_avail[Bicicleta_entrega].candado.ubicacion,
                Bike_avail[Bicicleta_entrega].danos),True,1)
        # with open('Devolucion_auto.json') as Devolucion:
        #     data_send_devolucion = json.load(Devolucion)
        #     data_send_devolucion['id_bike'] = Bike_avail[Bicicleta_entrega].iD
        #     data_send_devolucion['danos'] = Bike_avail[Bicicleta_entrega].danos
        #     data_send_devolucion['punto_de_prestamo'] = Bike_avail[Bicicleta_entrega].candado.ubicacion
        #     #### Enviar data_send_devolucion de carnet al SI, hacer un while para esperar confirmacion de receprcion
        Bike_avail[Bicicleta_entrega].persona.reset()
        timer_1.deinit()

def Interrupt_T2(timer_2):
    timer_2.deinit()
    vect_aux = ["Buenos", "dias"]
    for k in range(0, len(Bike_avail)):
        vect_aux[k] = Perifericos.lectura(k+2)
        if (vect_aux[k]!=None):
            Perifericos.servo_close(k+1)
    client.publish(b'Easyrun/Distribute',
        distribute(client_id, Bike_avail[0].persona.cedula, vect_aux, Bike_avail[0].candado.ubicacion),True,1)
    # with open('Prestamo_operario.json') as Prestamo_operario:
    #     data_send_devolucion = json.load(Prestamo_operario)
    #     data_send_prestamo_normal['cedula'] = Bike_avail[0].persona.cedula
    #     data_send_devolucion['id_bikes'] = vect_aux
    #     data_send_devolucion['punto_de_prestamo'] = Bike_avail[i].candado.ubicacion
    Bike_avail[i].persona.reset()


#Se dan las condiciones iniciales, no hay bicicletas en el puesto
Bike_avail[0].estado=True
Bike_avail[1].estado=True

Bike_avail[0].danos=False
Bike_avail[1].danos=False

Bike_avail[0].candado.estado = 'vacio'
Bike_avail[1].candado.estado = 'vacio'

disp.printLogo()
disp.printText('Easyrun', vspace=1, hspace=9)


#Abran el Jhonny



while True:
    ##Aqui va la revision de las interrupciones por hardware
    #Poner RST
    card_id_L_1  = Perifericos.lectura(1)
    if(card_id_L_1 != None):
        print (card_id_L_1)
        # with open('IDcarnet.json') as IDcarnet:
        #     data = json.load(IDcarnet)
        #     data['id'] = card_id_L_1  ###################### DATO PARA MANDAR POR WIFI EN SI1
        #     #### Enviar dato de carnet al SI, hacer un while para esperar la recepcion del dato y
        #     #### cuando este llegue seguir con el codigo
        # send_id(client_id, card_id_L_1)`
        client.publish(b'SI/Validate',send_id(client_id, card_id_L_1),True,1)
        time.sleep(1)
        client.check_msg()
        msg_received= msgFromSI()
        print(msg_received)

        with open('Prueba_persona.json') as Prueba_persona:
            data_prueba_persona = json.load(Prueba_persona)
        if(msg_received['ID'] != "0"): ##NO OLVIDAR: COMPARACIONES CON JSON SE HACEN EN STRING
            if(msg_received['User_Type'] == "Estudiante"):
                if((msg_received['Restriction'] != "True") and (msg_received['Current_Use'] == "False")):
                    
                    for i in range(0, len(Bike_avail)):
                        if ((Bike_avail[i].estado == False) and (Bike_avail[i].danos != True)):
                            Bike_avail[i].persona.cedula = data_prueba_persona['cedula']
                            #print(Bike_avail[i].estado != False)
                            disp.printText('                ', vspace=6, hspace=1)
                            disp.printText("Tome la bicicleta en "+ str(Bike_avail[i].candado.n_candado), vspace=5, hspace=1) #Fino
                            #mostrar en pantalla el numero de la bicicleta escogido

                            Perifericos.servo_open(i+1)
                            Bike_avail[i].candado.estado = 'en_espera'
                            Bike_avail[i].estado = True

                            Bicicleta_entrega=i
                            timer_1.init(period=10000, mode=machine.Timer.PERIODIC, callback=Interrupt_T1) #Activación de interrupción para prestamo
                            break
                else:
                    disp.printText('                ', vspace=6, hspace=1)
                    disp.printText('Tiene restricciones', vspace=5, hspace=1) #Fino
            elif (data_prueba_persona['user_type'] == "Operario"):
                if(data_prueba_persona['restricciones'] != "True"):
                    disp.printText('                ', vspace=6, hspace=1)
                    disp.printText('Puede retirar las bicicletas', vspace=5, hspace=1) #Fino
                    for i in range(0, len(Bike_avail)):
                        Bike_avail[i].persona.cedula = data_prueba_persona['cedula']
                        Perifericos.servo_open(i+1)
                        Bike_avail[i].candado.estado = 'en_espera'
                        Bike_avail[i].estado = True

                    timer_2.init(period=600000, mode=machine.Timer.PERIODIC, callback=Interrupt_T2) #Activación de interrupción para prestamo a operario
        else:
            disp.printText('                ', vspace=6, hspace=1)
            disp.printText('No esta registrado', vspace=5, hspace=1) #Fino
    else:
        disp.printText('                ', vspace=6, hspace=1)
        disp.printText('Acerque su carnet ', vspace=5, hspace=1) #Fino
        #print('El demorado soy yo')
#imprimir "acerque su carnet de nuevo"
        for k in range(0, len(Bike_avail)):

            card_id_Bike = Perifericos.lectura(k+2)
            #print ("El ", k+2, "      ",card_id_Bike)
            if(card_id_Bike != None):
                print(k+2, "Lector    ", card_id_Bike)
                if(Bike_avail[k].candado.estado == 'vacio'):

                    Perifericos.servo_close(k+1)
                    Bike_avail[k].candado.estado = 'ocupado'
                    print(Bike_avail[k].candado.estado)
                    Bike_avail[k].iD = card_id_Bike
                    Bike_avail[k].estado = False # No disponible(Prestada) = True/  Disponible(No prestada)= False
                    Bike_avail[k].danos = False # No dañada = False/ Dañada = True
                    with open('Devolucion_auto.json') as Devolucion:
                        data_send_devolucion = json.load(Devolucion)
                        data_send_devolucion['id_bike'] = Bike_avail[i].iD
                        data_send_devolucion['danos'] = Bike_avail[i].danos
                        data_send_devolucion['punto_de_prestamo'] = Bike_avail[i].candado.ubicacion
                        #### Enviar data_send_devolucion de carnet al SI, hacer un while para esperar confirmacion

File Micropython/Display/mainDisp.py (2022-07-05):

from displayLib import MyDisplay
from ili9341 import Display, color565
from machine import Pin, SPI
from xglcd_font import XglcdFont
from machine import SoftSPI
import math
import time

sck=18
mosi=23
miso=19

spi=SoftSPI(baudrate=1000000, polarity=0, phase=0, sck=Pin(sck, Pin.OUT), mosi=Pin(mosi, Pin.OUT), miso=Pin(miso, Pin.OUT))
disp=MyDisplay(spi)
#disp.printLogo()
disp.printShortText('Hola')
#disp.printText('UN Campus', vspace=1, hspace=8)

#print("Prueba Exitosa")

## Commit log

2022-04-15 Minor Changes
    [PowerModule.sch, Schematic.kicad_pcb, Schematic.sch]
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2022-04-27 Add files via upload
    Presupuesto del proyecto, componentes
    [Budget.xlsx]
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2022-04-28 ESP changed
    [Schematic.sch]
2022-04-29 Some changes on Power Controller
    [PowerModule.sch, Ramp_Generator.sch, Schematic.sch]
2022-04-29 Esquema Lectores
    Se agregan las conexiones de los 3 lectores en el esquemático
    [PowerModule.kicad_sch, Ramp_Generator.kicad_sch, Schematic.kicad_sch]
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2022-05-03 Motor Schematic
    Se incluye el esquemático del motor junto con algunas funciones, como condensador de bypass y elementos de antirrebote
    [Ramp_Generator.kicad_sch, Schematic.kicad_sch]
2022-05-03 Arreglo de Esquemático Lectores
    Se arregló el esquemático de los lectores, utilizando etiquetas para las conexiones
    [Schematic.kicad_sch]
2022-05-04 I2C interface added
    [Schematic.kicad_sch]
2022-05-04 Botones de reporte
    Se agregan los botones de reporte y se determinan los puertos que no serán utilizados
    [Schematic.kicad_sch]
2022-05-05 Arreglo I2C
    Se ponen junto a la interfaz I2C pines de alimentación que se podrán utilizar según las necesidades observadas
    [PowerModule.kicad_sch, Ramp_Generator.kicad_sch, Schematic.kicad_sch]
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2022-05-07 Huellas sin botones ni potencia
    [TestEasyrun.kicad_sch]
2022-05-08 Power integration
    Power integration
    [PowerModule.kicad_sch, TestEasyrun.kicad_sch]
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2022-05-09 3v3 Controller fixed
    [PowerModule.kicad_sch, TestEasyrun.kicad_sch]
2022-05-10 Old gate driver removed, looking for something else
    [PowerModule.kicad_sch, TestEasyrun.kicad_sch]
2022-05-10 Footprints added and new drivers designed
    [PowerModule.kicad_sch, TestEasyrun.kicad_sch]
2022-05-10 Almost all footprints added
    [PowerModule.kicad_sch, TestEasyrun.kicad_sch]
2022-05-10 PWM generator file
    [PWM_Generator_3v3.kicad_sch, PWM_Generator_5v0.kicad_sch, PowerModule.kicad_sch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]
2022-05-10 Botón de rst
    Se arreglaron las resistencias del botón de reset y enable
    [TestEasyrun.kicad_sch]
2022-05-10 Include the battery power module
    [Battery_Charge.kicad_sch, PowerModule.kicad_sch, TestEasyrun.kicad_sch]
2022-05-10 Change the global labels
    [Battery_Charge.kicad_sch, PWM_Generator_3v3.kicad_sch, PWM_Generator_5v0.kicad_sch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]
2022-05-10 Ready to merge
    [TestEasyrun.kicad_sch]
2022-05-10 Add conection changes
    Add conection changes, using different types of hierarchien
    [Report_buttons.kicad_sch, TestEasyrun.kicad_sch, actuators.kicad_sch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]
2022-05-13 Old schematic version deleted
    [PowerModule.kicad_sch, PowerModule.sch, Ramp_Generator.kicad_sch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]
2022-05-14 Some stuff deleted
    [Battery_Charge.kicad_sch, Buck3v3.kicad_sch, Easyrun.kicad_pcb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]
2022-05-14 Power Factor of Rectifier almost fixed
2022-05-14 Rectifier almost ready. Issues with current phase
2022-05-14 Power Module on schematic almost ready
    [Battery_Charge.kicad_sch, Boost_batt.kicad_sch, Buck3v3.kicad_sch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]
2022-05-14 Rprog changed
    [Battery_Charge.kicad_sch, Easyrun.kicad_sch]
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2022-05-14 Ferrite bead added
    [Easyrun.kicad_sch, PowerModule.kicad_sch]
2022-05-14 Organización PCB
    [Battery_Charge.kicad_sch, Boost_batt.kicad_sch, Buck3v3.kicad_sch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]
2022-05-14 Organización de PCB 2.0
    Se organizaron los componentes de la PCB
    [Easyrun.kicad_pcb]
2022-05-15 Mejor ruteo xd Felipe cambie las huellas
    [Battery_Charge.kicad_sch, Boost_batt.kicad_sch, Buck3v3.kicad_sch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]
2022-05-15 PCB distribution
    [Boost_batt.kicad_sch, Buck3v3.kicad_sch, Easyrun.kicad_pcb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]
2022-05-15 More free space schematic
    [Battery_Charge.kicad_sch, Boost_batt.kicad_sch, Buck3v3.kicad_sch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]
2022-05-16 Ruteo PCB
    Se agregó el archivo Easyrun_autoroute, con el ruteo de la PCB basado en autoroute :v
    [Easyrun.dsn, Easyrun_autoroute.kicad_pcb]
2022-05-16 Mounting holes
    [Boost_batt.kicad_sch, Easyrun.kicad_pcb, Easyrun.kicad_sch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]
2022-05-16 Cambio orden pines lectores y display
    Se cambiaron para facilitar el ruteo.
    [Battery_Charge.kicad_sch, Boost_batt.kicad_sch, Buck3v3.kicad_sch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]
2022-05-17 PCB almost ready
    [Easyrun.kicad_pcb]
2022-05-17 Ruteo de PCB
    Se agregó el ruteo de la PCB verificando las conexiones
    [Battery_Charge.kicad_sch, Buck3v3.kicad_sch, Easyrun.dsn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]
2022-05-17 Corrección tamaño de vías
    Se corrigió el tamaño de las vías pasantes de la PCB
    [Battery_Charge.kicad_sch, Boost_batt.kicad_sch, Buck3v3.kicad_sch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]
2022-05-19 Nothing, I guess
    [Easyrun.kicad_pcb]
2022-05-20 Gerber files were generated
    [Easyrun-B_Cu.gbr, Easyrun-B_Mask.gbr, Easyrun-B_Paste.gbr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]
2022-05-20 Cambio pines CS y Rst Display
    Se cambiaron los pines CS y Rst del Display que estaban en pines solo entrada de la ESP, por los pines STDBY y CHRG de la parte de potencia
    [Easyrun.kicad_pcb, Easyrun.kicad_sch]
2022-05-20 Archivos gerber y de taladro
    [Easyrun-B_Courtyard.gbr, Easyrun-B_Cu.gbl, Easyrun-B_Cu.gbr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]
2022-05-24 List of components generated
    [Easyrun.csv]
2022-05-28 Some tests
    [Easyrun.csv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]
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2022-05-30 Just some cleanup uwu
    [Battery_Charge.kicad_sch, PWM_Generator_3v3.kicad_sch, PWM_Generator_5v0.kicad_sch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]
2022-05-30 Changed some values on the schematic. Doesn't affect PCB
    [Battery_Charge.kicad_sch, Boost_batt.kicad_sch, Buck3v3.kicad_sch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]
2022-05-30 Updated values on PCB
    [Easyrun.kicad_pcb]
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2022-05-31 New transformer
    [Easyrun.kicad_pcb, Easyrun.kicad_sch, PowerModule.kicad_sch]
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2022-06-03 Budget almost ready
    [Boost_batt.kicad_sch, Budget.xlsx, Easyrun.csv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]
2022-06-03 The budget is ready i think
    [Budget.xlsx]
2022-06-04 Actualización del presupuesto
    Se actualizó el presupuesto con los conectores JST necesarios para el proyecto
    [Budget.xlsx]
2022-06-04 Buck converters simmulations
    [Boost_batt.kicad_sch, Buck3v3.kicad_sch, Budget.xlsx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]
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2022-06-04 Some formating in the budget
    [Budget.xlsx]
2022-06-04 Budget updated
    [Budget.xlsx]
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2022-06-06 Se realizaron arreglos en las clases creadas
    [Easyrun.py]
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2022-06-22 Compra de CP2102
    [Budget.xlsx]
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
